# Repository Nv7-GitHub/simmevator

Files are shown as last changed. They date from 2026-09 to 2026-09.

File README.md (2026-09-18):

# simmevator

An elevator tracker and floor display for Simmons Hall, MIT.

A barometer rides in each elevator car and works out which floor the car is on. It
broadcasts that over LoRa to a bridge in its own shaft, which relays it over
ESP-NOW to a screen on every landing of that shaft. Each screen shows the floor in
numbers you can read from down the corridor, an up/down arrow while the car is
moving, the transmitter's battery voltage, and how far that elevator has travelled
in the last day.

Three shafts are covered: A, B and C. A and C serve a basement as well as floors
1-10, so they have eleven landings each; B has ten. That is 3 transmitters, 3
bridges and 32 displays.

| | elevator A | elevator B | elevator C |
|---|---|---|---|
| landings | B, 1-10 | 1-10 | B, 1-10 |
| displays | 11 | 10 | 11 |
| LoRa frequency | 913.0 MHz | 915.0 MHz | 917.0 MHz |
| ESP-NOW channel | 6 | 1 | 11 |
| `txId` | `'A'` | `'B'` | `'C'` |

The three systems are independent end to end. A car is heard only by its own
bridge, a screen only ever sees its own shaft's car, and no packet crosses from one
shaft to another.

Each car node runs on a battery, unattended, for about seven weeks.

---

## How it works

### The hard part is not what you would guess

A floor is about 2.9 m of altitude, and a BMP390 resolves that easily — noise in
this shaft is 0.045 m, sixty times smaller. The difficulty is that **the reference
pressure moves.** Over a 3 h capture in this building the sea-level reference
wandered 9.9 m of apparent altitude, more than three floor heights. Any fixed
pressure-to-floor table slides through several floors in an evening.

So absolute altitude cannot decide the floor. Two facts rescue it:

- **A trip is short** — 5 to 60 seconds, over which the weather moves the
  reference by less than 0.05 m. The *change* in altitude across a trip is clean
  even when the absolute value is not.
- **Floors are a lattice.** Every jump between stops is an integer multiple of the
  floor pitch, so `round(jump / pitch)` is a strong error-correcting code.

The algorithm therefore reads floor *changes* from jumps between stops and treats
absolute position as a slowly-tracked side quantity. It learns the building as it
goes — the floor spacing, each landing's height, how many floors exist — with
nothing configured in advance. On the reference capture it converges in five
minutes to a pitch of 2.871 m and ten floors, and stays within ±1%.

The algorithm is not this repo's invention. It was developed and measured against
real data in the [`elevatormons`](../elevatormons) bring-up repo, and is fully
documented in `elevatormons/docs/ALGORITHM.md` — including the four approaches
that were tried and failed, which are more instructive than the one that worked.
This repo ports it to C++ and builds a system around it.

### Why the decision happens in the car

The node holds the sensor, so it sees an unbroken 1 Hz stream and decides the
floor locally. It broadcasts the answer, not the raw pressure.

That one choice makes radio loss harmless. A dropped packet can only *age* what a
screen shows; it can never corrupt the floor, because the next packet carries the
current floor outright. There is no state to resync and no way for a bad link to
produce a wrong number. If the bridge decided the floor instead, every dropout
would become a correctness problem.

### The three devices

```
  ELEVATOR CAR (battery)          MID-SHAFT (wall)          EVERY LANDING (wall)
  ┌──────────────────────┐        ┌──────────────┐          ┌──────────────┐
  │ XIAO ESP32S3         │        │ XIAO ESP32S3 │  ESP-NOW │ CYD x10/x11  │
  │  BMP390 @ 4 Hz       │  LoRa  │ + Wio-SX1262 │ ───────► │ ILI9341      │
  │  FloorMonitor @ 1 Hz │ ─────► │              │  flood   │ relay + draw │
  │  model in NVS        │913/915/│ LoRa -> mesh │ ch 6/1/11│              │
  │  battery sense       │917 MHz │ origin node  │ ◄──────► │ peer relay   │
  │  Wio-SX1262          │        └──────────────┘          └──────────────┘
  └──────────────────────┘
```

One of these per shaft, three times over. The column of radio settings is the only
difference between them.

**The transmitter** samples the barometer, runs the floor algorithm, and sends two
kinds of packet: an 8-byte `STATE` every 2 seconds while the car is moving, and a
24-byte `STATS` every 60 seconds carrying battery voltage, distance travelled, and
the learned building model.

**The bridge** does nothing but listen on LoRa and re-emit over ESP-NOW. It holds
no state worth losing.

**The displays** flood packets to each other so the signal reaches floors the
bridge cannot: every screen rebroadcasts each new sequence number exactly once, up
to eight hops. Flooding rather than a fixed 5→6→7 chain means one unplugged screen
does not cut off everything above it.

### Why the three systems do not interfere

**Separate LoRa frequencies, because three cars on one frequency is pure ALOHA.**
There is no carrier sense: a transmitter that is about to send has no idea another
shaft's car is mid-packet. A STATE packet is 297 ms and goes out every 2 s while
the car is active. STATE is not gated on motion alone - it keeps running for 10 s
past every stop - so the duty fraction is the 0.90 STATE-active figure, and each
car offers `0.5 x 0.90 = 0.45` packets per second. ALOHA's vulnerable window is
two packet lengths, `2 x 0.297 = 0.594 s`, so a given packet survives two
interferers with probability `exp(-2 x 0.45 x 0.594) = 0.586` - about two STATE
packets in five lost, on top of the 5.21% the shaft already costs
(`ALGORITHM.md` §9), and concentrated in exactly the evening peak when all three
cars are busy at once. So A, B and C sit on 913.0, 915.0 and 917.0 MHz: 2 MHz of
separation against a 125 kHz occupied bandwidth, sized for a transmitter passing
close to another shaft's bridge rather than for the typical case. A per-elevator
sync word would *not* fix this and must not be mistaken for a fix - it is checked
after demodulation, so it classifies wreckage rather than preventing it.
`docs/PROTOCOL.md` carries the full arithmetic.

**Separate ESP-NOW channels, because each mesh should stay the system that was
measured.** No display ever needs another shaft's data, so the three floods run on
channels 6, 1 and 11 and each one remains the ten- or eleven-node, single-origin
flood that `docs/MESH.md` measured and tuned - so every number in it stays valid as
written. One building-wide flood instead would break
in two ways: the per-bridge `origSeq` counters would collide, because the dedup ring
tests sequence numbers for equality with no notion of who minted them, so bridge
A's frame 4113 would silently swallow bridge C's; and the 5-40 ms relay jitter
window would be swamped, since 32 displays and 3 bridges put roughly 96
transmissions of about 1.3 ms each into a 35 ms window, some 3.5x oversubscribed,
re-creating the exact collision the jitter exists to prevent. Channel isolation
makes both problems not exist rather than patching them; the only thing given up is
cross-shaft path diversity, which is worthless when the shafts are far apart.
`docs/MESH.md` works through both.

### Why the update rate is what it is

Airtime is the entire power budget. A LoRa packet at SF10 costs hundreds of
milliseconds at about 118 mA, and the car in this building is *moving* 71% of an
evening peak. Thirty days off a 10 Ah LiFePO4 pack means staying under 40 mA
average. Send a 297 ms packet every 2 s around the clock and the radio alone is
~21 mA; stay awake between samples and the baseline is ~25 mA instead of ~3 mA.
Together that is ~47 mA - the requirement is missed before anything else has
gone wrong.

Two changes fix it without making the display feel slower:

- **Transmit only while the car is moving.** Nothing changes while it is parked,
  so there is nothing to say. A 60-second heartbeat carries the slow statistics
  and proves the transmitter is alive.
- **Detect motion at 4 Hz, run the algorithm at 1 Hz.** The stillness test gets
  fast samples so motion onset is caught within 250 ms and the first packet
  fires immediately; the algorithm itself still sees the 1 Hz stream its
  constants were tuned for. Between samples the chip light-sleeps, which is the
  difference between a 3 mA baseline and a 25 mA one.

That lands at roughly **23 mA average, about 50 days** on a 10 Ah LiFePO4 pack,
using the evening-peak traffic rate — a real week including nights does better.

That is arithmetic, not a measurement. No board has been on a meter yet, and the
light-sleep floor is the number in it I would trust least: the ~3 mA is the
datasheet figure, while the actual XIAO board also carries a power LED and a
charge IC. The spec lists the four unmeasured draws and what to do about them.

### One correction to the radio settings

`elevatormons/platformio.ini` configures the barometer link at **BW62.5 kHz**, but
`ALGORITHM.md §9` records that the actual field run — the one that measured 5.21%
packet loss over three hours in this shaft — was at **BW125 kHz and only 14 dBm**.

This project uses BW125 at 22 dBm on all three shafts. The 915.0 MHz that the
bring-up repo and the field run used is now elevator B's frequency specifically -
A and C sit 2 MHz either side of it, and nothing else about the link differs
between them. That is the configuration with real in-shaft
evidence, running with 8 dB more margin than the run that produced the 5.21%
figure, and it costs 297 ms per packet instead of 725 ms. The same section notes
that loss barely tracks signal-to-noise (r = −0.13) — it is shadowing and
interference, not a decode floor — so buying margin with a higher spreading factor
would cost airtime linearly and buy very little.

---

## What each screen shows

```
┌────────────────────────────┬──────────────┐
│                            │      ▲       │
│      ██████     ██         │    UP        │
│      ██  ██     ██         │              │
│      ██  ██     ██         │  12.7 V      │
│      ██  ██     ██         │  ■■■■■□      │
│      ██████     ██         │              │
│                            │  2.1 mi      │
│                            │  today       │
└────────────────────────────┴──────────────┘
```

The floor number is drawn as vector segments rather than a font — anything large
enough to read at distance looks soft as a bitmap. While the car is moving the
number sweeps through the intermediate floors and the arrow lights up; on arrival
it snaps to the floor the algorithm confirmed.

Battery voltage and the 24-hour distance come from the transmitter once a minute,
so every screen in that shaft agrees. Between heartbeats each screen extrapolates
the distance from floor changes it observes, so the number ticks in real time
rather than jumping once a minute.

If a screen stops hearing the mesh it dims, then greys out and turns its onboard
LED amber — a dead link is visible from the corridor rather than silently showing
a floor from twenty minutes ago.

That is normal operation. There are three further states that appear only while a
shaft is being commissioned or is misconfigured, all derived from fields the wire
already carries: **LEARNING**, showing how many landings the car has spanned so far
over the word `LEARNING` and `OF 11`; **ANCHORING**, asking for a ride to both ends of the shaft
after the transmitter restored its model from NVS; and **CHECK SHAFT**, which means
the car is confidently reporting a floor count this shaft does not have. The last
one is the whole reason the others exist. An elevator A car commissioned over a
period in which nobody presses B learns a span of ten landings, is internally
consistent, sets its model ready, and would label every screen in the shaft one
floor too low indefinitely - and it is the display, holding the only copy of how
many landings the building has, that can catch it. That mismatch is CHECK SHAFT's
only cause, and because every display in a shaft carries the same label table and
hears the same bridge, it appears on all of them at once or on none. It does not
catch a mis-flashed display: the mesh channels are 6, 1 and 11, which do not
overlap, so a display flashed for the wrong shaft never hears its landing's bridge
at all and sits on the splash screen forever. `docs/FLASHING.md` has the
commissioning procedure. `--` means "this screen has heard frames but has no
confirmed floor"; a screen that has heard nothing since boot still shows the
splash.

---

## Documentation

| Document | What is in it |
|---|---|
| [Design spec](docs/superpowers/specs/2026-09-11-simmevator-design.md) | The whole system: power budget, protocols, verification gates, parts list |
| [Three-elevator deployment](docs/superpowers/specs/2026-09-18-three-elevator-deployment-design.md) | The per-shaft frequency and channel plan, the basement, the commissioning screens |
| [docs/HARDWARE.md](docs/HARDWARE.md) | Wiring, the battery divider, the buck regulator, antenna placement |
| [docs/FLASHING.md](docs/FLASHING.md) | Which firmware goes on which board, and how |
| [docs/PROTOCOL.md](docs/PROTOCOL.md) | Both wire formats, field by field |
| [docs/MESH.md](docs/MESH.md) | How the ESP-NOW flood behaves and how to debug it |
| [docs/ALGORITHM_PORT.md](docs/ALGORITHM_PORT.md) | How the C++ port maps to the Python reference, and the evidence it matches |
| `elevatormons/docs/ALGORITHM.md` | The algorithm itself — the source of truth, not maintained here |

---

## Building

PlatformIO. Nine firmware environments - three roles across three elevators:

```bash
pio run -e elevator_tx_b   -t upload    # shaft B's car node
pio run -e bridge_rx_b     -t upload    # shaft B's bridge
pio run -e floor_display_b -t upload    # each of shaft B's screens
pio test -e native                      # host unit tests
```

Substitute `_a` or `_c` for the other two shafts. The suffix is the whole of an
image's identity: it carries the LoRa frequency, the ESP-NOW channel, the `txId`
and the floor label table, so a display built `_b` and hung in shaft A is deaf on
channel 1 while that landing's bridge floods channel 6, and never leaves its splash
screen. There is no runtime elevator selection to correct it with.
`docs/FLASHING.md` has the which-image-on-which-board table, the board labelling,
and the commissioning check that catches exactly that mistake.

The port is verified by replaying the real 3 h capture through the actual C++
implementation and diffing it against the Python reference sample by sample:

```bash
pio run -e sim && .pio/build/sim/program sim/cpp_broadcasts.csv
python3 sim/compare_to_python.py sim/cpp_broadcasts.csv
```

The gate that matters is the first line of the comparator's output: the C++
floor sequence has to be identical to the Python's over all 10,950 samples. Five
numeric gates bound the rest - ten floors, 2.871 m pitch ±1 mm, 3409 m travelled
±0.1%, 357 floor-to-floor moves ±1, 255 confirmed stops ±1.

`ALGORITHM.md` §5 reports 356 moves and 256 stops, and that is not a
disagreement: §5 measured the raw capture, which is a radio log with 49 dropouts
in it, while the replay runs the gap-filled 1 Hz stream the node would actually
have been handed. The Python reference produces 357/255 on that input too.
`docs/ALGORITHM_PORT.md` §6 works through it.

---

## What this will not do

- **There is no absolute anchor.** The floor index is integrated from jumps, so a
  rounding that goes wrong stays wrong until the car happens to correct it. An
  absolute readout from a tracked datum was tried and is measurably worse.
- **It is safe to about 3 hPa/h of pressure change** with the floor count still
  exact, and degrades rather than diverges past that. A typical weather front is
  1–2 hPa/h; the fastest rate in the reference capture was 0.88 hPa/h.
- **Turbulence headroom is roughly 1.5–2×** a confirmed gusty evening. Not zero,
  not large.
- **The constants are tuned to this building and this sensor.** They are measured,
  not universal.
- **Battery voltage is ±2–3% before calibration**, about ±0.4 V at 12 V. Enough to
  answer "does this need charging?", not a fuel gauge.
- **The 24-hour window is relative to uptime**, not wall-clock — there is no RTC.
  After a reboot it reports less than a day of history and says so.
- **A screen shows one car.** A landing served by all three shafts needs three
  screens, one per shaft. There is no "which car arrives first" logic anywhere in
  the system, and there cannot be without building one: each display is on its own
  shaft's mesh channel and physically never hears the other two cars.

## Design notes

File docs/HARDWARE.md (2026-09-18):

# Building the hardware

Three device types, built in this order: the transmitter (the only one with any
wiring in it), the bridge (twenty minutes, mostly deciding where to put it), and
the displays (unbox, plug in).

Three shafts, not one. Elevators A and C have a basement landing and eleven
displays each; elevator B is the ten-landing shaft this system was first built
for, and is unchanged in every respect.

| device | where it lives | power | what it does |
|---|---|---|---|
| transmitter ×3 | on top of / inside each elevator car | LiFePO4 4S pack | reads the barometer, decides the floor, transmits LoRa |
| bridge ×3 | one per shaft, floor 5 (section 6) | USB-C wall adapter | receives LoRa, floods it over ESP-NOW |
| display ×32 | one per landing per shaft: A 11, B 10, C 11 | USB-C wall adapter | shows the floor, relays the mesh |

**The three builds are mechanically identical.** Nothing in sections 2 to 5
differs between A, B and C - the same stack, the same divider, the same buck,
the same calibration procedure, the same charger, the same enclosure. The only
thing that differs is which firmware image goes on the board, and which shaft
the finished board is carried to. So those sections are written once and mean
all three; where one says "the transmitter", build three of them.

Everything below is drawn from the design spec
(`docs/superpowers/specs/2026-09-11-simmevator-design.md`), the three-elevator
deployment spec
(`docs/superpowers/specs/2026-09-18-three-elevator-deployment-design.md`),
`platformio.ini`, and the module headers in `src/`. Where a number is not from
one of those, it says so.

---

## 1. Parts

Reproduced from spec section 3.6. This list has already been trimmed once - see
the note after the tables before you add anything back.

**Transmitter (×3 assemblies; the Qty column is per assembly)**

| Part | Qty | Notes |
|---|---|---|
| Seeed XIAO ESP32S3 | 1 | |
| Seeed Wio-SX1262 for XIAO | 1 | stacks onto the XIAO; ships with its 915 MHz antenna |
| BMP390 breakout | 1 | Adafruit 4816 or equivalent |
| LiFePO4 12.8 V 10 Ah pack with BMS | 1 | 4S; BMS required |
| LiFePO4 charger, 14.6 V | 1 | a Li-ion or lead-acid charger will not terminate correctly |
| MP1584EN 5 V buck module | 1 | meter it at 5 V **before** connecting the XIAO |
| Resistor 100 kΩ 1% | 1 | divider top |
| Resistor 20 kΩ 1% | 1 | divider bottom |
| Spade terminal pair | 1 | so the pack can come off for charging |
| Hookup wire / JST leads | — | |

No divider filter cap (oversampled in software instead), no buck input
electrolytic (the node averages ~23 mA, so the module's own ceramics are
sufficient), and no inline fuse (the pack's BMS covers overcurrent). The
enclosure is 3D printed.

**Bridge (×3, one per shaft; Qty is per bridge)**

| Part | Qty |
|---|---|
| Seeed XIAO ESP32S3 | 1 |
| Seeed Wio-SX1262 for XIAO | 1 |
| USB-C 5 V adapter + cable | 1 |

**Displays (×32, all three shafts)**

| Part | Qty | Notes |
|---|---|---|
| ELEGOO ESP32 CYD 2.8" ILI9341 240×320 | 32 | sold in 2-packs → 16 packs |
| USB-C 5 V / 1 A adapter | 32 | |
| USB-C cable | 32 | |

32, not 30: **A 11 + B 10 + C 11 = 32**, because A and C each have a basement
landing and B does not. Count the landings, not the shafts - ordering 30 because
"three tens" is the easy mistake, and it leaves the two basements dark.

Mounts are 3D printed.

**Totals to buy:** 6 × XIAO ESP32S3 · 6 × Wio-SX1262 · 3 × BMP390 · 3 × battery +
charger · 3 × MP1584EN · 6 × resistors · 3 × spade pair · 32 × CYD · 35 × USB-C
supplies. Three enclosures and 32 display mounts are printed.

The USB-C count is 32 displays + 3 bridges = 35; the transmitters run off their
packs and take no adapter. Note that the build does not simply triple: the
electronics scale ×3, but the displays scale ×3.2, and the displays are the bulk
of the parts count. The two basement landings are the whole of that difference.

### 1.1 Where is the fuse?

The four things a reader usually expects to find in this list and does not:

| left out | why |
|---|---|
| inline fuse | the pack's BMS is the overcurrent and undervoltage protection. It is inside the pack, on the cell side of the terminals, and it is the reason the pack has to be a BMS pack rather than four bare cells. |
| buck input electrolytic | the node averages ~23 mA. The MP1584EN module's own input ceramics handle that; the electrolytic is there for modules running amps. |
| filter cap across the divider bottom leg | the reading is taken once a minute off a rail that moves over hours. The filtering is done in software instead: 32 samples, median not mean (spec 3.2, `battery.h`). A median also throws away the occasional wild sample the S3's SAR ADC produces, which a capacitor would not. |
| barrel jack, separate antennas, enclosure, display mounts | the Wio-SX1262 ships with its antenna; the three enclosures and the 32 mounts are 3D printed; the pack connects through spade terminals so it can come off for charging without a connector in the middle. |

If you decide to add the fuse anyway, put it on the pack side of the spade pair
so it protects the wiring and not just the buck.

### 1.2 Tools

Not in the parts list, but you cannot do section 3 without them:

- **A multimeter.** Non-negotiable. Section 3.4 is entirely a meter procedure.
- Soldering iron, thin solder, heat-shrink.
- A small flat screwdriver or trimmer tool, if your buck module has a trimpot
  rather than a fixed 5 V output.
- Wire strippers, and a crimp tool if your spade terminals are crimp type.
- A USB-C cable for flashing - and a habit of not having it plugged in at the
  same time as the pack (section 3.5).

---

## 2. Transmitter pinout

Everything the car node uses, in one table. From spec 3.1, `lora_link.h`, and
`platformio.ini`.

| signal | XIAO pad | GPIO | where it comes from |
|---|---|---|---|
| BMP390 SDA | D4 | 5 | your wire |
| BMP390 SCL | D5 | 6 | your wire |
| SX1262 SCK / MISO / MOSI | D8 / D9 / D10 | 7 / 8 / 9 | the stack, no wire |
| SX1262 NSS / DIO1 / BUSY / NRST | - | 41 / 39 / 40 / 42 | the stack, no wire |
| battery sense | D0 | 1 (ADC1_CH0) | your divider |
| 5 V in | 5V | - | the buck |
| ground | GND | - | common with the pack minus |

The BMP390 runs on `Wire1` at 400 kHz, address 0x77. The radio is SF10 / BW125 /
CR4-8 at 22 dBm on all three systems; only the centre frequency differs - 913.0
MHz on A, 915.0 MHz on B, 917.0 MHz on C, for the collision reasons in spec 2.1.
That is a build flag, not a wiring difference. The board you solder is the same
board whichever shaft it ends up in.

---

## 3. Transmitter assembly

Build in this order. Each step is testable before the next one adds a way for
it to fail.

### 3.1 Stack the radio onto the XIAO

The Wio-SX1262 is an expansion board for the XIAO form factor. There is no
wiring: the SPI bus and the four control lines in the table above all run
through the two 7-pin headers.

1. Match the silkscreen. **D0 must sit over D0 and GND over GND.** Both boards
   label their pads; check two on opposite corners before you press them
   together, because the headers will physically mate either way round and the
   wrong way puts the pack rail onto a control line.
2. Press them home evenly. They should sit flat with no gap.
3. Screw the 915 MHz antenna that came with the Wio-SX1262 onto its connector.
   It is a band antenna, not a spot-tuned one, and 913.0 / 915.0 / 917.0 MHz all
   sit deep inside the 902-928 MHz ISM band - so the same antenna serves all
   three shafts and there is nothing to select here.

**Do not power the radio without the antenna attached.** That is general RF
practice rather than anything measured here - an unterminated PA reflects its
own output back into itself.

Also, from the note in `platformio.ini` next to `LORA_TX_POWER=22`: the
SX1262's absolute maximum RF input is around **+10 dBm**, and the transmitter
puts out 22 dBm. On a bench the only thing between those two numbers is path
loss, and at 915 MHz free space gives:

| separation | at the receiver |
|---|---|
| 0.10 m | +10.3 dBm - **over the absolute maximum** |
| 0.25 m | +2.4 dBm |
| 0.50 m | -3.6 dBm |
| 1.00 m | -9.7 dBm - about 20 dB of margin |

The crossover is 0.104 m. **Keep at least 1 m between any transmitter antenna
and any bridge antenna whenever both are powered**, which is a minimum and not a
target - further is always safer. Two boards side by side on a bench sit 5-10 cm
apart, which is past the absolute maximum, and what it costs is a damaged
receiver front end that then under-performs quietly rather than failing
outright. The bench test in `FLASHING.md` is written around this minimum.

### 3.2 BMP390, four wires

| BMP390 breakout | XIAO |
|---|---|
| VIN | 3V3 |
| GND | GND |
| SDA (SDI on Adafruit's silkscreen) | D4 |
| SCL (SCK on Adafruit's silkscreen) | D5 |

Leave SDO alone. Floating or pulled high gives address 0x77, which is what
`platformio.ini` sets. If your breakout straps it low you get 0x76, and
`bmp390BringUp()` falls back to that address and reports the mismatch on the
serial console rather than hiding it - so a board strapped the other way still
works, it just tells you.

Keep the leads short. The bus runs at 400 kHz and there is no reason for it to
be longer than it needs to be.

Sensor placement matters more than it looks. `bmp390_sensor.h` notes that this
is the module the 3 h reference capture was taken with, and that the Bosch
indoor-navigation preset it configures (x8 pressure, x2 temperature, IIR 3,
~5 cm of altitude noise) is what every constant in `floor_monitor.h` was tuned
against. The stillness threshold is 0.08 m, sitting in the gap between ~0.05 m
of stop noise and a car doing up to 1.78 m/s (ALGORITHM.md sections 2 and 5).
Substituting a noisier part - a BMP280, say - does not degrade the system
gracefully, it invalidates the tuning. Fit the BMP390.

Mount the sensor near where the enclosure's vent will be (section 3.6) and not
pressed against the buck module. The vent is what lets it see shaft pressure at
all; sitting it on the warmest thing in the box is an unmeasured risk rather
than a measured one, but it costs nothing to avoid.

### 3.3 The battery sense divider

From spec 3.2:

```
  BATT+ ──[ R1 = 100 kΩ 1% ]──┬── D0 (GPIO1)
                            │
                       [ R2 = 20 kΩ 1% ]
                            │
  BATT− ──────────────────── ┴── GND (common with XIAO GND)
```

Ratio 6.0. Use 1% parts: the ratio is the calibration, and section 4 corrects
one unit's error, not a drifting one.

What the ADC pin actually sees, computed from that ratio:

| pack | pin | meaning |
|---|---|---|
| 14.6 V | 2.433 V | a charger at its termination voltage |
| 13.3 V | 2.217 V | rested full |
| 12.8 V | 2.133 V | CHARGE SOON, ~20% remaining |
| 12.0 V | 2.000 V | CHARGE BATTERY, ~10% remaining |
| 10.0 V | 1.667 V | BMS cutoff territory |

The whole span sits inside the ESP32-S3 ADC's linear region at 12 dB
attenuation, which misbehaves below ~0.15 V and above ~2.8 V. That is the point
of this ratio: not to use the full scale, but to keep both ends of
the pack's range comfortably inside the part of the range that behaves, with
headroom at the top for a charger that overshoots.

Divider draw is ~122 µA at 14.6 V, which is about 0.5% of the ~23 mA average
the 30-day budget is built on - roughly a quarter of a day off the ~50-day
figure. That is why there is no switching MOSFET across it -
the switch would cost more parts and more ways to fail than it saves.

**Why kilohms and not megohms.** With no filter capacitor, the ADC's internal
sample capacitor charges straight through the divider's Thevenin resistance -
R1 ∥ R2, ~16.7 kΩ here. At 1 MΩ / 200 kΩ that would be ~167 kΩ, slow enough
that each sample can read low and pick up more noise. The ratio, and so every
voltage in the table above, is unchanged.

**Why D0 and not somewhere else.** D0 = GPIO1 = ADC1_CH0 is the only free ADC1
pad on this board:

| pad | taken by |
|---|---|
| D4 / D5 | the BMP390's I²C bus |
| D8 / D9 / D10 | the radio's SPI |
| GPIO39 / 40 / 41 / 42 | the radio's DIO1, BUSY, NSS, NRST |

It has to be ADC1 rather than any ADC. `battery.h`: ADC2 is unusable while WiFi
is active, and while the car node itself does not run WiFi, the bridge and the
displays do - the constraint is written into the shared design so the choice is
the same everywhere.

There is deliberately no capacitor here. See section 1.1.

### 3.4 Check the buck regulator's output

The buck feeds the XIAO's **5V pad**, not its 3V3 pad. The 3V3 pad is the
output of the XIAO's own regulator, so driving it means fighting that regulator;
the 5V pad is the board's supply input, which that regulator exists to convert.

> ### STOP. This is the step that destroys hardware.
>
> The module is sold as a fixed 5 V output, but check it before you believe it.
> Some MP1584EN boards carry a trimpot instead, and one of those arrives set to
> **whatever position it was left in on the production line**. The adjustment
> range runs from under a volt to within shouting distance of the input, so fed
> from a 12.8 V pack a mis-set module can put far more than 5 V onto the pad.
>
> The XIAO's own regulator stands between that pad and the chip, so it takes
> the hit first - but it is an SGM6029, rated for 5.5 V in. There is almost no
> headroom above 5 V, and past it the failure reaches the silicon behind it.
>
> **Meter the output with nothing connected to it. Only then wire it to the
> XIAO.**
>
> Check the XIAO ESP32S3 datasheet's input rating before you decide a reading
> is close enough; this document deliberately does not quote you a number to
> feel comfortable about.

Procedure:

1. Disconnect the buck's output from **everything**. No XIAO, no BMP390, no
   divider top leg. Nothing but two bare wires.
2. Wire the pack to the buck input through the spade pair, minding polarity.
   IN+ to pack positive, IN− to pack negative.
3. Meter across the buck's OUT+ and OUT−, DC volts, on a range that covers
   15 V - not a 3 V range that will just say "OL" if the output is high.
4. It should read **5.0 V**. If it does and the board has no trimpot, you are
   done with this step.
5. If the board does have a trimpot, turn it in small increments and watch the
   meter. Do not assume which way is up, and do not assume a quarter turn will
   do anything: some of these modules carry multi-turn trimmers and take many
   revolutions to cross the range. Turn, read, turn, read. Land on **5.0 V**.
6. Disconnect the pack. Wait, re-connect, and confirm it still reads 5 V.

The MP1584 is PWM-only with no light-load PFM mode (spec 3.3), so it does not
pulse-skip and the no-load reading you just took is representative of the
loaded one. Re-measure once with the node running anyway, at the XIAO's 5V pad
rather than at the buck, so the measurement includes your wiring.

That same PWM-only behaviour is why the node's ~3 mA light-sleep current is
served badly by this module. It runs ~80-85% at the ~23 mA average. A TPS62203
or MP2338 would recover a few days. Not required.

### 3.5 Wire the buck to the XIAO, and never plug in USB at the same time

Only after section 3.4 reads 5 V:

1. Buck OUT+ → XIAO **5V** pad.
2. Buck OUT− → XIAO **GND**, and the same ground node as the divider's bottom
   leg and the pack minus. One ground, not two.
3. Divider top leg to pack positive on the buck-input side of the spade pair,
   so the divider measures the pack and not the buck.

The power chain, end to end (spec 3.3):

```
LiFePO4 4S 10 Ah → spade terminals → MP1584EN buck at 5 V → XIAO 5V pad
  → XIAO's onboard SGM6029 buck → 3.3 V for the chip, the radio and the BMP390
```

**The second conversion costs about a tenth of the battery.** The XIAO's
onboard regulator is an SGM6029 synchronous buck - not a linear regulator - with
a power-save mode and 2.3 µA of quiescent current, so at these loads it is worth
roughly 85-90% rather than the 66% a linear part would manage. Behind the
module's own ~85%, the pack sees about 7.9 mA for the node's 23 mA average,
which is ~50 days against the ~56 the same node would get if the 3.3 V rail
could be fed directly. Feeding 3V3 would recover those few days at the cost of
back-driving that regulator, which is why it is not done here. Both efficiency
figures are datasheet-grade estimates, not measurements.

> **USB and the buck must never be connected at the same time.**
>
> The XIAO's 5V pad and its USB connector's VBUS are the same node. Connect
> both and the buck's output is tied directly to the host's 5 V rail - two
> supplies across each other, and the buck's output is also back-fed into
> whatever you are flashing from.
>
> The 12.8 V pack has the energy to keep doing that indefinitely. It may
> survive; it may take out the buck, the XIAO, or the USB port on your
> computer. It is not a failure with a predictable outcome, which is exactly
> why it is not worth characterising empirically on your only XIAO.
>
> **Unplug the pack at the spade terminals before you plug in USB.** Every
> time. That is what the spade pair is for as much as charging is.

### 3.6 The enclosure must be vented

The enclosure is 3D printed, so this is a note for whoever draws it.

**A sealed box turns the barometer into a thermometer and the system stops
working.** Inside a sealed volume the pressure the BMP390 reads is set by the
temperature of the air trapped with it, not by the altitude of the car. Every
constant in the algorithm is measured against shaft pressure.

What is needed is modest: a small hole with a scrap of foam or filter cloth
over it. It has to equalise on the timescale of seconds, not breathe freely.
The car moves a floor in a couple of seconds and the algorithm's stillness
window is 5 samples at 1 Hz, so a vent with a time constant of seconds is
invisible to it and a vent with a time constant of minutes is fatal to it.

Design notes for the print:

- Vent placed away from the buck module, and near where the BMP390 sits.
- Cloth or foam over the hole - it is there to keep dust and drafts off the
  sensor port, not to seal.
- The pack comes out for charging, so the spade pair has to be reachable
  without dismantling the electronics.
- The antenna wants to be outside the box, or at least not wrapped in it.

---

## 4. Calibrating the battery reading

Uncalibrated, the divider is worth ±2-3%, about ±0.4 V at 12 V (spec 9). That
answers "does this need charging?" and is not a fuel gauge. A one-point
correction with a DMM gets most of it back, and it takes two minutes.

The firmware applies a plain integer ratio to the computed pack voltage:

```
reported_mV  =  pin_mV × (R1 + R2) / R2 × VBAT_CAL_NUM / VBAT_CAL_DEN
```

`VBAT_CAL_NUM` and `VBAT_CAL_DEN` both default to 1 in `platformio.ini`, which
means uncalibrated.

**Procedure**

1. Assemble the node and power it from the pack. Let it settle - a pack just
   off the charger is still relaxing.
2. Meter the pack directly at the spade terminals. Write it down in millivolts.
   Call it `TRUE`.
3. Read what the node thinks. The serial console is the place to get it: the
   display's readout is rounded to 0.1 V (spec 6) and that is too coarse to
   calibrate against. Call it `REPORTED`.
4. Set:

```
-DVBAT_CAL_NUM=TRUE
-DVBAT_CAL_DEN=REPORTED
```

5. Rebuild and reflash (pack disconnected - section 3.5).
6. Re-read. It should now agree with the DMM to within the ADC's own noise.

**Worked example.** The DMM reads 13.28 V at the terminals. The node reports
13112 mV. Then:

```
-DVBAT_CAL_NUM=13280
-DVBAT_CAL_DEN=13112
```

and the node's next reading becomes 13112 × 13280 / 13112 = 13280 mV. The
correction is 1.28% high, which is exactly the order of error the ±2-3%
uncalibrated figure predicts.

Use the raw millivolt integers. Do not reduce them to a rounded percentage -
the maths is integer division, and `13280/13112` carries more resolution than
`101/100` does. The intermediate is computed in 64-bit, so there is no headroom
problem with numbers this size.

This is **per unit**, and there are now three units. It corrects the resistors
you actually soldered and the eFuse calibration curve of the chip you actually
have, so each of the three transmitters carries its own pair of numbers and they
will not agree with each other.

Nothing in the firmware can tell the boards apart, which is what makes this
worth a warning rather than a footnote: a ratio measured on A's board and
compiled into C's image does not fail, it reports a confidently wrong pack
voltage on eleven screens, and it does so most convincingly near the thresholds
in section 5 where the curve is flat. Record which pair belongs to which shaft,
in the repo, alongside that elevator's other build flags - the per-elevator
transmitter environments are the natural place for them.

---

## 5. Charging the pack

**14.6 V LiFePO4 charger. Nothing else.**

| charger type | why not |
|---|---|
| Li-ion / LiPo | charges to 4.2 V per cell. A 4S Li-ion charger terminates around 16.8 V, which is well above the 14.6 V a 4S LiFePO4 pack wants. |
| lead-acid / "12 V car battery" | wrong termination behaviour. Lead-acid chargers hold a float voltage indefinitely and some apply temperature compensation or an equalise stage; LiFePO4 wants constant current to 14.6 V, then to be left alone. |

Those chemistry voltages are standard figures, not measurements from this
project. The one number this project does specify is the 14.6 V termination in
spec 3.6.

The pack's BMS will defend itself against a lot of this, and you should not
make it. A BMS disconnecting on overvoltage mid-charge is a fault condition,
not a charging strategy.

**Disconnect the pack at the spade terminals before charging.** The spade pair
exists for exactly this.

What the rest of the system does while it is off, and when it comes back:

| | screens |
|---|---|
| pack off | keep the last floor for 2.5 min, dim, then at 3 min grey out with the LED amber. A CHARGE BATTERY warning stays red throughout |
| pack back on | within a minute the STATS heartbeat arrives, the screens un-grey, and a charged pack clears the battery warning. No pairing, nothing to press |
| until the car visits **both ends of its own shaft** | the screens read **ANCHORING / RIDE TO BOTH ENDS** in place of the floor |
| after that | normal |

ANCHORING is deliberate, and it is not a fault: it is the screen saying the
model came back out of flash intact but the car's position is not yet known, and
it clears itself the moment the car has seen both ends. The transmitter keeps
the learned building across a reboot, but not the car's position: the car may
have moved and the weather will
have shifted the pressure reference, and a floor restored one out would stay one
out forever. Seeing both ends of the shaft fixes the position exactly. **So
after reconnecting, ride to the lowest landing and the highest.**

Which landings those are is per shaft. In B they are floors 1 and 10. In A and C
the bottom end is the **basement**, not floor 1: stopping at floor 1 leaves the
seen span one landing short of the learned span, the anchor never locks, and the
screens go on reading ANCHORING indefinitely. That is the failure mode to watch
for - not a wrong floor, but a shaft where the request on the glass never goes
away because the ride it asks for was never completed. Either order works - bottom-then-top and top-then-bottom are the same operation, and
neither the code nor the procedure prefers one.

It does not correct itself over time without that, and it does not need to - the
first time the car naturally visits both ends it locks in.

### Voltage to state of charge

From spec 3.2, set in `battery.h` as `VBAT_WARN_MV` / `VBAT_CRITICAL_MV` /
`VBAT_CHARGED_MV`:

| voltage | what every screen shows | notice at ~23 mA |
|---|---|---|
| 13.3 V | rested full - clears any warning | - |
| **12.8 V** | **CHARGE SOON**: amber badge in place of the battery bar, voltage in amber | ~3 days (~20% left) |
| **12.0 V** | **CHARGE BATTERY**: steady red banner across the bottom, red badge, onboard LED steady red | under 2 days (~10% left) |
| ~10 V | the BMS disconnects the pack and the car node goes silent | - |

Each 10% of a 10 Ah pack is about 1.8 days at the budgeted draw, so these give
less notice than the voltages suggest. An earlier version warned at 12.0 V
believing it was ~20%; it is nearer 10%.

The warning **latches**. Once a reading crosses a threshold the level stays up,
even if a later reading wobbles back above it, and clears only when the pack
reads 13.3 V - which in practice means it has been charged. A warning that
disappeared by itself would be the easy one to miss. The latch lives on the
transmitter, and the level travels in the STATS flags, so every screen in that
shaft agrees - eleven of them in A and C, ten in B. It travels no further than
that: the three meshes are on separate channels, so a flat pack in A is invisible
on B's and C's screens, as it should be.

A warning also does not grey out when the link goes stale, although everything
else on the screen does. If the car node goes silent right after CHARGE BATTERY,
the likeliest reason is that the battery ran out, and that is the moment the
warning should stay on the screen.

The thresholds sit on the flat part of the curve, where ±2-3% uncalibrated
accuracy is about ±0.4 V. **Do the one-time calibration** (above) or CHARGE SOON
may come days early or not until CHARGE BATTERY.

Expect to charge roughly every seven weeks if the node is behaving: spec 2
budgets ~23 mA average at evening-peak traffic, which is ~50 days through the
module and the XIAO's own regulator, against a 30-day requirement.

---

## 6. Bridge

Mechanically trivial, and the three are built identically. The only decision is
where each one goes.

1. Stack the Wio-SX1262 onto the XIAO exactly as in section 3.1, silkscreen
   matched, antenna screwed on.
2. Flash it with the image for its shaft - `bridge_rx_a`, `bridge_rx_b` or
   `bridge_rx_c`. The environment carries that shaft's LoRa frequency and mesh
   channel, so a bridge flashed with the wrong image does not degrade, it hears
   nothing at all - and because its mesh channel is wrong too, its displays
   never hear a frame either and sit on the splash screen. `FLASHING.md` has
   the table and the upload commands; do not keep a second copy of them here.
3. Label the board with its shaft letter before it leaves the bench, in the same
   motion as flashing it (section 7).
4. Plug it into a USB-C 5 V adapter on floor 5 of its own shaft. It sits in
   continuous LoRa receive and floods what it hears over ESP-NOW, so it wants to
   stay powered.

**Antenna placement is the part that matters.** ALGORITHM.md section 9 measured
the link and found that loss barely tracks SNR at all (r = −0.13): 5.21% batch
loss over 3 h, 49 dropouts, and even above +6 dB of margin there is still 0.3%
loss. That is shadowing and interference, not a decode floor - which is why
this project spends power on bandwidth and TX power rather than on spreading
factor.

The exception is floor 9. It is the one landing whose SNR range crosses the
SF10 decode floor, bottoming at −2.0 dB against a healthy +14.2 dB median. An
intermittent shadow, and section 9's own conclusion is that it is addressable
by antenna placement rather than by spreading factor.

So:

- Favour line of sight up the shaft. The bridge is on floor 5 and the problem
  landing is above it.
- Get the antenna out of the cabinet, out from behind the steel door, away from
  the ductwork.
- Vertical, and clear of large metal for as much of its length as you can
  manage.
- If floor 9 still shows staleness in service, move the bridge antenna before
  you touch any radio setting. The measurement says placement is the lever.

The bridge also has to reach at least one display over ESP-NOW, since it is the
origin of the flood. In practice the floor 5 display is next to it, so this is
rarely a constraint - but do not put the bridge somewhere the mesh cannot
follow it.

### 6.1 Is floor 5 still the middle when the shaft has a basement?

Worth doing the arithmetic rather than assuming, because A and C have an extra
landing at the bottom and the instinct is to compensate by dropping their
bridges to floor 4.

Count landings, not floor numbers. B's shaft has ten landings, an even count, so
there is no single middle one: the centre falls between floors 5 and 6, and
floor 5 was chosen of the two deliberately, because the weak landing sat above
and biasing upward cost nothing. A and C have eleven landings, an odd count, so
there **is** an exact middle landing - the sixth. Counting up from the bottom:
B, 1, 2, 3, 4, 5. The sixth landing is floor 5.

| shaft | landings | count | middle | bridge | landings above | landings below |
|---|---|---|---|---|---|---|
| A | B, 1-10 | 11 | the 6th = floor 5 | floor 5 | 5 | 5 |
| B | 1-10 | 10 | between floors 5 and 6 | floor 5 | 5 | 4 |
| C | B, 1-10 | 11 | the 6th = floor 5 | floor 5 | 5 | 5 |

**Floor 5 is still the right answer, and in A and C it is a better one than it
is in B** - it is the exact centre rather than the lower of two candidates. The
extra landing at the bottom moves the midpoint down by half a landing, from
halfway between floors 5 and 6 to floor 5 itself. Half a landing is not a
relocation. Dropping those bridges to floor 4 would move them away from the
centre and away from the upper shaft at the same time, for no gain.

The furthest any display sits from its bridge is therefore 5 landings in all
three shafts, which is what section 7's hop-limit slack is computed against.

One caution about floor 9. `ALGORITHM.md` section 9 is a 3 h capture in **one**
shaft, taken when this was a one-shaft building. It says where that shaft's
shadow was; it does not predict where A's or C's will be, because steel,
ductwork and cabinet placement differ landing by landing. Carry the shape of the
finding into the other two shafts - one or two landings will be markedly worse
than the median, and the fix is antenna placement rather than a radio setting -
but do not carry the coordinate. Each shaft reveals its own weak landing in
service, by the greyed-out screen and amber LED in section 7.

---

## 7. Displays

32 ELEGOO CYD boards across three shafts - eleven in A, ten in B, eleven in C.
USB-C power and nothing else: no wiring, no soldering, no sensors. Flash each one
with its shaft's image (`floor_display_a`, `floor_display_b` or
`floor_display_c`), mount it, and plug it into a 5 V / 1 A adapter. The upload
commands and the which-image-on-which-board table are in `FLASHING.md`.

**Label every board with its shaft letter before it leaves the bench.** Not
afterwards, not from memory - in the same motion as flashing it, while the
programmer is still attached. The image sets both the mesh channel and the
label table, and nothing on the outside of a CYD says which it got.

A board flashed for the wrong shaft is **deaf**, not wrong. The mesh channel is
part of the image - 6 for A, 1 for B, 11 for C - and 1, 6 and 11 are the
non-overlapping channels, so such a board cannot hear its landing's bridge at
all. It never leaves `displaySplash("Simmevator", "waiting for the mesh")`: a
screen that simply never comes up. That is the whole protection, and it is a
good one precisely because it fails visibly: the first time the board is
powered on its landing with the shaft running, it is obviously dead next to
neighbours showing floors. What it cannot tell you is *which* shaft the board
was built for, and it cannot tell you anything at all at the bench, where every
board is out of range of its bridge and shows the same splash. The written
letter is what tells you the shaft, which is why it goes on in the same motion
as the flash.

CHECK SHAFT is not the defence here and cannot be: a deaf board renders nothing
to check. CHECK SHAFT is a statement about the **car**, not the display - the
car's learned `nFloors` disagrees with the shaft's `FLOOR_LABEL_COUNT`, in
practice a car that has never visited its lowest landing. Every display in a
shaft carries the same label table and hears the same bridge, so CHECK SHAFT is
all-or-nothing across the shaft: it appears on every screen at once or on none.
One odd screen out of ten or eleven is never CHECK SHAFT.

**The mesh is the constraint on where they go.** There is no WiFi network here
and no router. Every display has to hear either its bridge or another display in
its own shaft directly, over ESP-NOW on that shaft's channel - 6 for A, 1 for B,
11 for C - and then relay onward. Spec 4.2:

- Flood rules are identical on the bridge and every display in that shaft; each
  node relays each new `origSeq` exactly once.
- Hop limit 8. Five landings is the furthest any display sits from its bridge in
  any of the three shafts (section 6.1), so 8 leaves slack for a detour around a
  dead node.
- `WIFI_PROTOCOL_LR`, Espressif's long-range PHY, is worth about 7 dB over
  802.11b - which is the margin that makes floor-to-floor through concrete
  work at all.

Which means:

- **Do not mount a display inside a metal enclosure.** A shielded box around an
  antenna defeats the mesh, and because the flood is multi-hop it does not just
  break that one screen - it can remove the path the screens above it were
  relying on.
- **Do not put one behind a steel fire door** and expect it to hear the bridge
  through it.
- Prefer a position in the corridor with a path toward the stairwell or the
  shaft, and toward the floors above and below.
- The 3D-printed mounts should hold the board with its back open to the
  corridor, not sandwiched against a steel frame.

**The three meshes never help each other.** They are on separate channels by
design, so a display in A cannot be rescued by a well-placed display in C however
close the two shafts pass. Each shaft's mesh has to stand up on its own, and a
mounting survey is a per-shaft exercise repeated three times, not one walk of the
building.

A display that cannot hear anything is not silent: it greys out and turns its
RGB LED amber after 180 s without a STATS packet (spec 6). That is how you find
a bad mounting position - walk each shaft's landings and look at the LEDs.

Power draw is small enough that a 1 A adapter is generous, and the LDR on
GPIO34 handles night dimming on its own, so the board does not need to be
positioned for a light switch.

---

## 8. Pre-power-on checklist

Run this on **each** transmitter with the pack **disconnected**, before it is
ever connected. Each line is here because getting it wrong costs a board. Three
transmitters means running it three times; it is not a checklist you pass once
for the design.

| # | check | how | pass looks like |
|---|---|---|---|
| 1 | No shorts on the pack rail | meter in continuity/resistance across the spade pair, pack off | not a short. You should read roughly the divider's 120 kΩ in parallel with whatever the buck input looks like. A beep here means stop. |
| 2 | Polarity, pack to buck | trace IN+ to pack positive and IN− to pack negative by eye and by meter | the buck's silkscreen agrees with the wires |
| 3 | Ground is one node | continuity: XIAO GND to buck OUT− to divider bottom leg to pack minus | all four beep together |
| 4 | **Buck output is 5 V** | section 3.4, with the output disconnected from everything | 5.0 V on the meter, checked after a power cycle |
| 5 | Buck output polarity | OUT+ goes to the **5V** pad, not 3V3, not any signal pad | read the silkscreen twice |
| 6 | Divider ratio is sane | meter R1 and R2 in circuit: ~100 kΩ top, ~20 kΩ bottom | ratio near 6.0. If R1 and R2 got swapped the pin sees 5/6 of the pack - over 10 V straight onto a 3.3 V pin. |
| 7 | Divider tap goes to D0 | continuity from the R1/R2 junction to the D0 pad | beeps, and does **not** beep to D1, 3V3 or GND |
| 8 | Nothing on D4/D5 but the BMP390 | visual | SDA to D4, SCL to D5, not crossed |
| 9 | Antenna attached | visual | screwed down before any power |
| 10 | **USB unplugged** | visual | see section 3.5 |
| 11 | **This is the right shaft's firmware** | the startup banner's `[tx] txId='B' (0x42) @ 915.0 MHz` line names the elevator letter and the LoRa frequency it was built for. A car node prints no mesh channel - it has no ESP-NOW radio in its build (`tx_base` leaves `espnow_mesh.cpp` out) | the letter matches the car this node is about to go into, and the frequency is that shaft's - 913.0 for A, 915.0 for B, 917.0 for C |

Then, in order:

1. Connect the pack at the spade terminals.
2. Meter the XIAO 5V pad against GND with the node running. Still 5 V. The
   3V3 pad, now an output, should read 3.3 V.
3. Check the serial console: the BMP390 should come up (and say which address
   it found), and `batteryBegin()` prints the divider and calibration
   configuration it was compiled with.
4. Meter the pack at the terminals and compare with what the node reports. If
   the two disagree by more than a few percent, go back to check 6 before
   reaching for section 4 - a calibration ratio will happily paper over a
   wrong resistor and leave you with a reading that is right at one voltage and
   wrong everywhere else.

Only when all of that passes does the node go in the car - and only into the car
whose letter check 11 printed.

### 8.1 Before any board goes on a wall

The bridges and the displays have no pack, no divider and no buck, so none of the
checks above apply to them. They have exactly one failure mode worth a checklist,
and it is the one that does not announce itself.

| # | check | how | pass looks like |
|---|---|---|---|
| 1 | The board in your hand carries a shaft label | visual, on the board itself | a letter, written at the programmer (sections 6 and 7) |
| 2 | That letter is the shaft you are standing in | visual | they match. An unlabelled board goes back to the bench, not on the wall - there is no way to read a CYD's build from its case |
| 3 | For a display, the landing exists in that shaft's table | visual | a board going onto a basement landing belongs to A or C; B has no basement |
| 4 | The shaft has exactly one bridge | count | two bridges on one channel collide in the `origSeq` space, which the bridge console warns about but nobody is watching |

Then let the car run normally for a while and walk the landings: every screen in
the shaft should show a floor rather than CHECK SHAFT - and CHECK SHAFT here
means the car, not the board in front of you, because it appears on the whole
shaft at once or not at all (section 7). A single screen still on the splash
while its neighbours show floors is the mis-flash case instead. That is the acceptance
test for the whole shaft, and it is deliberately read off the screens rather than
off a console - during a commissioning run the car is on its pack, and section
3.5 forbids a USB cable anywhere near the transmitter while it is. `FLASHING.md`
has the procedure and what each screen state means.

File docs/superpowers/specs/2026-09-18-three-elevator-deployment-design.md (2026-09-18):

# Three elevators: A, B and C

Deploying this system across three shafts instead of one, where two of them
have a basement.

The guiding constraint: **elevator B must behave exactly as the single-elevator
system does today.** Every change here is either a per-elevator build flag or a
new state that only appears when something is misconfigured. There is no change
to either wire format, no change to the algorithm, and no change to the normal
operating UI.

---

## 1. What is actually being deployed

| | elevator A | elevator B | elevator C |
|---|---|---|---|
| landings | B, 1-10 | 1-10 | B, 1-10 |
| landing count | 11 | 10 | 11 |
| transmitters | 1 | 1 | 1 |
| bridges | 1 | 1 | 1 |
| displays | 11 | 10 | 11 |

Three transmitters, three bridges, 32 displays. The three shafts are far apart
in the building, but far apart is not a guarantee - LoRa at 22 dBm carries a
long way indoors, and ESP-NOW on the 802.11 LR PHY is more sensitive than
ordinary WiFi. The design assumes all three systems can hear each other and
makes that harmless, rather than assuming they cannot and finding out later.

---

## 2. The frequency and channel plan

| | elevator A | elevator B | elevator C |
|---|---|---|---|
| `LORA_FREQUENCY` | 913.0 MHz | **915.0 MHz** (unchanged) | 917.0 MHz |
| `MESH_CHANNEL` | 6 | **1** (unchanged) | 11 |
| `ELEV_TX_ID` | `0x41` `'A'` | `0x42` `'B'` | `0x43` `'C'` |
| `FLOOR_LABEL_COUNT` | 11 | **10** (unchanged) | 11 |
| `FLOOR_LABELS` | `B,1..10` | **`1..10`** (unchanged) | `B,1..10` |

Everything else - spreading factor, bandwidth, coding rate, sync word, TX power,
preamble, hop limit, repeats, jitter, dedup depth - is identical on all three
systems and unchanged from today.

### 2.1 Why the LoRa link needs separate frequencies

Three cars on one frequency is pure ALOHA with no carrier sense. A STATE packet
is 297 ms and goes out every 2 s while the stream is active. The right duty
figure is **0.90, the STATE-active fraction, not the 0.712 moving fraction** -
the 2026-09-11 spec §2.2 makes this correction in bold, and for the same reason
it matters here: STATE is not gated on motion, it runs for
`STATE_HOLD_AFTER_STOP_MS` (10 s) past every stop, and those packets are the
same 297 ms at the same 22 dBm and collide identically. So each car offers
`0.5 x 0.90 = 0.45` packets per second. ALOHA's vulnerable window is two packet
lengths, `2 x 0.297 = 0.594 s`, so the probability a given STATE packet survives
two interferers is

```
P(survive) = exp(-2 x 0.45 x 0.594) = exp(-0.5346) = 0.586
```

**About two STATE packets in five are lost**, on top of the 5.21% the shaft
already costs (`ALGORITHM.md` §9), and concentrated in exactly the evening peak
when all three cars are busy simultaneously. That is not a degradation the
display's staleness logic is designed to absorb.

(`exp(-2G)` assumes Poisson arrivals and STATE is a periodic 0.5 Hz stream, so
this is an estimate rather than a prediction. It does not need to be better than
that: both the figure above and the one the moving fraction would give are
decisively against sharing a frequency, which is the only decision it informs.)

**A per-elevator sync word does not fix this and must not be mistaken for a
fix.** The sync word is checked after preamble detection and demodulation; it
filters frames that were already received successfully. It does nothing to stop
two 22 dBm carriers from destroying each other in the air. Frequency separation
is the only mechanism here that prevents collisions rather than merely
classifying the wreckage.

2 MHz of separation against a 125 kHz occupied bandwidth is roughly 16 channel
widths. That margin is chosen against the near-far case - a transmitter in one
shaft at close range to another shaft's bridge - not against the typical case,
where the shafts are far apart anyway. 913.0 / 915.0 / 917.0 all sit inside the
902-928 MHz ISM band with wide margin to both edges, and the modulation,
occupied bandwidth and duty cycle are unchanged from the single-elevator
deployment, so nothing about the regulatory picture changes.

The sync word stays 0x34 on all three. Changing it would buy nothing real and
is one more per-elevator value to get wrong.

### 2.2 Why the ESP-NOW meshes are separated by channel

No display ever needs another shaft's data. Isolating the three floods on
channels 1, 6 and 11 means **each mesh is exactly the ten-node, single-origin
system that was already measured and tuned**, so every number in `MESH.md`
remains valid as written.

The alternative - one building-wide flood carrying elevator-tagged frames -
creates two problems that would then have to be solved:

1. **`origSeq` collides.** Three bridges each mint a monotonic u16 into one
   flood. Bridge A's frame 4113 and bridge C's frame 4113 are indistinguishable
   to `meshDedupSeenOrInsert()`, which tests equality against a ring of recent
   values with no notion of who minted them. The second one is dropped as a
   duplicate. Not once - continuously, at random, forever. Fixing it means an
   origin field in the envelope and a `MESH_VERSION` bump.
2. **The relay jitter stops working.** `MESH_REPEATS` is 3 and the jitter window
   is 5-40 ms. With 32 displays and 3 bridges, a single frame reaching every
   node produces around 96 transmissions contending for a 35 ms window, each
   about 1.3 ms long - roughly 3.5x oversubscribed. `MESH.md` §5 is explicit
   that the jitter window existing at all is the difference between a mesh that
   works and one that does not; oversubscribing it re-creates precisely the
   collision it was introduced to prevent.

Channel isolation makes both problems not exist, rather than patching them. It
costs nothing that is wanted: the only thing given up is cross-shaft path
diversity, which is worthless when the shafts are far apart.

A side benefit worth recording: because `MESH_CHANNEL` is per-elevator, any one
shaft can be moved to a different channel independently if a site survey finds
its channel congested (`MESH.md` §11). The only rule is that two shafts within
earshot must not share a channel.

### 2.3 Why the mesh needs no elevator field

Adding an elevator id to the mesh envelope was considered and rejected. With the
floods on separate channels, a display physically cannot receive another shaft's
frames, so the field would never discriminate anything at runtime.

The same fact disposes of the failure it would have guarded. A display flashed
for the wrong shaft is not shown the wrong car - it is **deaf**. It sits on a
channel its landing's bridge does not transmit on, hears nothing at all, and
stays on the boot splash. That is the loudest failure available: a screen that
never comes up is noticed on the day it is installed, which is exactly when
somebody is standing in front of it. An elevator field in the envelope would be
one byte spent to detect a condition in which no bytes arrive.

`MESH_VERSION` therefore stays 1, `MESH_MAGIC` stays 0x5E1E, and the envelope is
byte-for-byte what is deployed today.

---

## 3. `txId`, and the bridge's foreign-packet filter

`txId` has been in both LoRa formats since the beginning, reserved for exactly
this. It is now meaningful: `'A'`, `'B'` or `'C'` as ASCII, so that a hex dump
reads `E0 42 ...` and identifies the shaft without a lookup table. That choice
is for the benefit of someone decoding a capture in a stairwell, which is the
audience `PROTOCOL.md` is written for.

`bridge_rx.cpp` does not look at `txId` today - `handleFrame()` checks the tag,
dispatches on it, and wraps whatever arrives. It gains one check: a packet whose
`txId` is not this bridge's elevator is dropped and counted in a new
`dropForeignTxId` counter, alongside the existing `dropTagCount` and
`dropLenCount`.

With 2 MHz of separation that counter should read 0 forever. **That is the
point.** A non-zero value is unambiguous evidence of cross-shaft leakage rather
than an inference from a loss statistic, and it is the pass condition for the
bench test in §7.2.

The bridge continues to strip `txId` before wrapping, exactly as
`meshWrapLora()` does today. Displays still never see it. Nothing downstream of
the bridge changes.

### 3.1 The pre-existing foreign-origin warning

`bridge_rx.cpp:295` already warns when it hears a mesh frame on its channel that
it did not mint, with the text *"a second origin on channel N would collide in
the origSeq space"*. That guard was written for the single-elevator system and
happens to be exactly the instrument that detects two bridges accidentally
sharing a channel. It needs no change, but it does need documenting as a
deliberate part of the three-elevator verification story.

---

## 4. The basement, and the commissioning readout

This is the part that is a correctness problem rather than a configuration
problem, and it deserves the most care.

### 4.1 The failure

`floor` index 1 is defined as *the lowest landing ever seen*, not as a name. The
model is learned at runtime from confirmed stops. If elevator A is commissioned
over a period in which nobody presses B, the model learns a span of 10 landings,
sets `modelReady`, and starts broadcasting confident floor indices 1-10 - which
the display maps onto labels `B,1,2,...,9`.

**Every label on all eleven of A's displays is then one floor too low,
indefinitely, and looks entirely plausible.**

Nothing inside the algorithm can detect this. `anchorStep()` exists to resolve an
unknown *offset* after an NVS restore, and it locks when the span of indices seen
since boot equals the learned span (`floor_monitor.h:879-900`). In this failure
the learned span is 10 and the seen span is 10; they agree. The model is
internally consistent and wrong.

The only thing in the system that knows the building has eleven landings is
`FLOOR_LABEL_COUNT` on the display. So the check must live there.

### 4.2 Why the check cannot live on a console

The obvious commissioning step - read `nFloors` off a serial console - is
unusable in this building:

- **The bridge console is unreachable in practice.** It is a wall-powered box
  mid-shaft. Reading it means standing at it with a laptop, but the answer is
  only known after a full end-to-end run, by which time the person is elsewhere.
- **The transmitter console is forbidden.** `HARDWARE.md` §3.5 requires that USB
  is never plugged in while the buck is feeding the XIAO's 5V pad. A
  commissioning run happens with the car on battery, which is precisely the
  condition under which no USB cable may be attached.

During the exact procedure that needs verifying, there is no serial port
anywhere in the system. The displays are the only instrument available, so the
verdict has to be rendered on them.

### 4.3 The four states, from fields already on the wire

`elevator_tx.cpp:270` sends `floor = 0` whenever `modelReady` is clear, and
`floor_monitor.h:1032` sets `b.modelReady = modelReady() && !positionUnknown_` -
so the learning case and the post-restore anchoring case are indistinguishable
from STATE alone. `ELEV_FLAG_NVS_RESTORED` in STATS separates them, which is the
"restored and trusted versus learned here" distinction `PROTOCOL.md` §3 already
describes that flag as existing for.

| `nFloors` | `MODEL_READY` | `NVS_RESTORED` | screen |
|---|---|---|---|
| `< labelCount` | 0 | 0 | **LEARNING** - big digits show `nFloors`, the word `LEARNING` and `OF 11` beneath |
| `== labelCount` | 0 | 1 | **ANCHORING** - words, not digits: ride to both ends |
| `== labelCount` | 1 | - | normal operation |
| `!= labelCount` | 1 | - | **CHECK SHAFT** - the off-by-one trap |

No wire change. No new flag. No reserved bit spent.

**All three inputs must be taken from STATS.** `MODEL_READY` is also in STATE,
and reading it from there is wrong in a way that is not obvious: STATE only runs
while the car moves plus a 10 s hold, so on a display that booted into a parked
shaft it is false because nothing has arrived, not because the car said
anything. Combined with an `nFloors` that did arrive, that reads as "full span,
not ready" - ANCHORING - so every screen in a healthy parked shaft would ask to
be ridden to both ends after any display reset. One packet, one snapshot.

The last row is the one that matters: a model that is ready and confident but
reports a floor count the building does not have. **It has exactly one cause** -
a car that has never reached its lowest landing - and it necessarily appears on
every screen in the shaft at once, because every display in a shaft carries the
same label table and hears the same bridge.

A display carrying the wrong shaft's label table is *not* a second cause, though
it looks like one. Such a display is on the wrong mesh channel too, so it hears
nothing and renders nothing (§2.3). CHECK SHAFT on one screen out of eleven is
not a diagnosis to plan for - it cannot happen.

### 4.4 What the count readout is, and is not

`nFloors()` is `maxIndex() - minIndex() + 1` (`floor_monitor.h:530`) - **the span
of learned indices, not a tally of landings visited.** Two consequences the
documentation must state plainly, because the obvious reading is wrong:

- **It is not a progress bar.** An express run from the basement to floor 10
  produces indices 1 and 11 and the readout jumps straight from 2 to 11. It will
  not tick 3, 4, 5.
- **It is only meaningful once pitch is established**, which needs ordinary
  multi-stop traffic rather than one long run.
- **It must not be shown as a bare number.** The learned span of a shaft being
  commissioned runs 2..11, which is exactly the range of real floor labels, and
  it is drawn in the same seven-segment glyphs the floor number uses. Without
  the word `LEARNING` at a size that survives corridor distance, a passer-by
  reads the count as the floor the car is on. The `OF 11` caption does not
  carry that on its own - it is the first thing to stop resolving as you walk
  away.

So the commissioning instruction is *"let the car run normally for a while, then
check that every screen in the shaft shows a floor rather than CHECK SHAFT"* -
not *"watch it count up"*.

### 4.5 Order does not matter

Bottom-then-top and top-then-bottom are the same operation.
`floor_monitor.h:888` already says so for the restore case: *"ride to the bottom
floor and the top floor, in either order."* For the fresh-learn case the span
grows regardless of direction. Neither the procedure nor the code prefers a
direction, and the documentation should say so explicitly so that nobody invents
a ritual.

### 4.6 `--` does not go away

`--` remains correct for "frames are arriving but there is no confirmed floor",
which is a different condition from all four states above and must not be given
a number.

A display that has heard *nothing* since boot is a third thing again, and it
does not show `--` either: `floor_display.cpp` only calls `displayUpdate()` once
a frame has arrived, so until then the boot splash stays on the glass. Three
conditions, three appearances - splash for "nothing has ever arrived", `--` for
"arriving, no floor yet", and the commissioning screens for "arriving, and the
model and the building disagree".

### 4.7 Rendering the basement label

No rendering change is needed. `segmentsFor()` in `display_ui.cpp:97` already has
a seven-segment glyph for `'B'`, and `DISPLAY_MAX_LABELS` is 32, so an
eleven-entry label table fits with room to spare. This was verified by reading
the code, not assumed.

---

## 5. Code changes

Deliberately small. Every item is either a build flag or a new state that only
appears when something is misconfigured.

### 5.1 `platformio.ini`

Three new per-elevator sections holding four values each:

```ini
[elev_a]
build_flags = -DLORA_FREQUENCY=913.0f -DMESH_CHANNEL=6 -DELEV_TX_ID=0x41
[elev_b]
build_flags = -DLORA_FREQUENCY=915.0f -DMESH_CHANNEL=1 -DELEV_TX_ID=0x42
[elev_c]
build_flags = -DLORA_FREQUENCY=917.0f -DMESH_CHANNEL=11 -DELEV_TX_ID=0x43
```

`LORA_FREQUENCY` and `MESH_CHANNEL` are already defined in `[lora_base]` and
`[mesh_base]`. The per-elevator value must win. Since both are consumed through
`#ifndef` guards in `lora_link.h` and `espnow_mesh.h`, a duplicate `-D` on the
command line is a redefinition warning at best and a silent wrong value at
worst. **The base sections must stop defining the per-elevator values entirely**,
so that each value is defined in exactly one place, and a missing elevator
section is a compile error rather than a silent fallback to B's numbers.

Nine firmware environments: `elevator_tx_{a,b,c}`, `bridge_rx_{a,b,c}`,
`floor_display_{a,b,c}`. `default_envs` lists all nine. `native` and `sim` are
unchanged.

The label flags move from `[env:floor_display]` into the per-elevator display
envs: A and C get `FLOOR_LABEL_COUNT=11` and `FLOOR_LABELS="B,1,...,10"`, B keeps
10 and `1,...,10`.

### 5.2 `src/bridge_rx.cpp`

- `dropForeignTxId` counter next to `dropTagCount` / `dropLenCount`.
- In `handleFrame()`, after the tag check and before dispatch: read `txId` at
  `ELEV_OFF_TXID` and drop if it is not `ELEV_TX_ID`, logging the offending
  value and the RSSI in the same style as the unknown-tag path.
- The counter appears in `printSummary()`.
- The startup banner prints which elevator, frequency and channel this build is
  for, so a console session immediately reveals a mis-flashed bridge.

### 5.3 `src/display_ui.h` / `src/display_ui.cpp`

- `DisplayUiState` gains `uint8_t modelFloors` and `bool modelFloorsValid`.
- A commissioning state enum derived from those plus the existing `modelReady`
  and an `nvsRestored` flag that must also be plumbed through.
- Rendering for LEARNING (count in the big digits, `OF n` beneath), ANCHORING
  (text) and CHECK SHAFT (text), reusing the existing centred-message path
  rather than inventing a new layout.

### 5.4 `src/floor_display.cpp`

- `applyStats()` already unpacks `nFloors` and `flags` and throws both away
  after a `Serial.printf`. Capture `s.nFloors`, `elevStatsNvsRestored(&s)` and
  `elevStatsModelReady(&s)` into statics.
- `buildUiState()` populates the new fields. Note that `modelReady` for the
  commissioning decision is the STATS copy, while `positionValid` keeps using
  the STATE copy - see §4.3 for why crossing the two breaks a parked shaft.
  These are two different questions: "may this node animate right now" follows
  STATE, "what did the car last say about its model" follows the heartbeat.
- The startup banner names the elevator this build is for.

### 5.5 `src/elevator_tx.cpp`

- `ELEV_TX_ID` loses its `#define ELEV_TX_ID 1` fallback at line 86-87, so that
  building a transmitter without an elevator selected fails loudly.
- The startup banner already prints `txId`; it should print it as a character.

### 5.6 Tests (`test/`)

New host-side coverage, run by `pio test -e native`:

- an eleven-entry label table parses, and index 1 is `B`
- the four commissioning states are selected correctly from every relevant
  combination of `nFloors`, `modelReady` and `nvsRestored`
- a `txId` that is not this elevator's is rejected; one that is, is accepted
- `'B'` has a non-zero seven-segment glyph

---

## 6. Documentation changes

| file | change |
|---|---|
| `README.md` | three elevators, the deployment table, the per-shaft radio plan |
| `docs/PROTOCOL.md` | §1 gains the frequency plan; `txId` is no longer "only one car exists"; a new section on the three-system collision analysis and why sync words are not the answer |
| `docs/MESH.md` | the channel plan and the isolation argument; why not one flood; the `origSeq` and jitter arithmetic from §2.2; §11's survey becomes per-shaft |
| `docs/FLASHING.md` | nine environments, the which-image-on-which-board table, board labelling, the commissioning procedure, the four screen states, the bench coexistence test |
| `docs/HARDWARE.md` | 3x parts, per-shaft bridge placement, eleven-landing shafts |
| `docs/ALGORITHM_PORT.md` | untouched - the algorithm does not change |

---

## 7. Verification

### 7.1 Every link, and why it does not collide

The table the documentation must carry, one mechanism per row:

| communication | competes with | isolation mechanism | observable |
|---|---|---|---|
| car X -> bridge X (LoRa) | cars Y, Z | 2 MHz frequency separation | bridge loss statistics |
| car Y -> bridge X (LoRa) | - | frequency, then `txId` filter | `dropForeignTxId` (bench) |
| bridge X -> displays X (ESP-NOW) | bridges Y, Z | separate channels 1/6/11 | `foreignOrigins` (bench) |
| display <-> display within X | its own shaft | unchanged jitter and dedup | `MeshCounters` |
| mesh X | building WiFi on that channel | per-shaft site survey | `MESH.md` §11 procedure |
| LoRa (915 MHz) | ESP-NOW (2.4 GHz) | different band | none needed |

### 7.2 Bench coexistence test

All three transmitters and all three bridges powered at once, on a bench, with
laptops attached.

**Keep every board at least 1 m from every other board.** This is a minimum, not
a maximum, and it is a hardware limit rather than a matter of taste. The
SX1262's absolute maximum RF input is about +10 dBm (`HARDWARE.md` §3.1) and the
transmitters run at 22 dBm, so in free space at 915 MHz:

```
  0.10 m  ->  +10.3 dBm    over the absolute maximum
  0.25 m  ->   +2.4 dBm
  0.50 m  ->   -3.6 dBm
  1.00 m  ->   -9.7 dBm    about 20 dB of margin
```

The crossover is 10.4 cm. Six boards "on one table" is exactly how two of them
end up 5 cm apart, and the damage is to a receiver front end rather than to the
test.

**What this proves, and what it does not.** Equidistant boards are a near-far
ratio of zero, so this is not the worst case - it is the case where every
foreign signal arrives at the *same* power as the wanted one. That is a real
stress on adjacent-channel rejection, and far harsher than the typical building
geometry where a foreign car is much further away than your own. But the genuine
worst case - a foreign car a metre from your bridge while your own car is ten
floors up the shaft - is not reproducible on a bench, and this test should not
be described as though it were.

Pass conditions:

- each bridge's `publishCount` advances at its own car's cadence
- each bridge's `dropForeignTxId` stays at 0
- **no** `foreignOrigins` field appears in any bridge's summary line -
  `printSummary()` prints that counter only when it is non-zero, so the pass
  condition is its absence, not a printed zero
- no bridge's loss statistics degrade when the other two are powered versus when
  they are not

This is where `dropForeignTxId` earns its place, because a laptop is attached.

### 7.3 Instrument honesty

**`dropForeignTxId` and `foreignOrigins` are bench instruments, not field
instruments.** Both live in the bridge console, which §4.2 establishes is
unreachable during normal operation. The documentation must say so rather than
implying field visibility that does not exist. In the field, the argument for
non-interference is the frequency and channel separation, plus the fact that a
filtered foreign packet degrades to silence rather than to a wrong floor.

The field instruments are the displays: §4.3's four states.

### 7.4 Build and test verification

- `pio test -e native` - all existing tests plus §5.6, on the host
- `pio run` - all nine firmware environments compile
- a check that the nine environments actually differ: extract
  `LORA_FREQUENCY`, `MESH_CHANNEL`, `ELEV_TX_ID` and `FLOOR_LABEL_COUNT` from
  each built environment and confirm they match the table in §2. A build matrix
  that silently collapses to three identical images is the most likely way this
  change goes wrong, and it is invisible in a passing build.

---

## 8. What is deliberately not being done

- **No mesh envelope change.** No elevator field, no `MESH_VERSION` bump. §2.3.
- **No LoRa format change.** Both formats are byte-identical to today.
- **No per-elevator sync word.** §2.1 - it does not prevent collisions.
- **No shared display showing all three cars.** One display per elevator per
  floor, so the existing single-car UI is unchanged.
- **No runtime elevator selection.** Identity is a build flag. The mitigation
  for a mis-flashed board is §4.3's CHECK SHAFT state plus physical labelling,
  not a touch-screen picker.
- **No anchoring progress on the wire.** The seen-span is not transmitted and
  will not be. Spending a reserved `state` bit on a condition that resolves
  itself in one round trip is not worth the wire surface.

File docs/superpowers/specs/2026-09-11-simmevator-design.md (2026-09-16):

# Simmevator — elevator floor tracker and per-floor displays

Design spec. Simmons Hall, MIT.

A barometer in the elevator car decides which floor the car is on and broadcasts
it over LoRa to a bridge on floor 5, which floods it over ESP-NOW to a display on
every floor. The car node runs on a battery for at least a month.

The floor-detection algorithm is not designed here. It exists, it is measured, and
it is specified in `../../../../elevatormons/docs/ALGORITHM.md` with a reference
implementation in `elevatormons/tools/floor_algorithm.py`. This spec covers
porting it faithfully to C++ and building a system around it. **The algorithm's
tuning constants are not to be re-tuned.**

---

## 1. Why the system is shaped this way

Three constraints drive every decision below.

**The floor decision must happen in the car.** ALGORITHM.md §9: the node holds the
sensor, so it sees an unbroken 1 Hz stream. Radio loss can only age what a display
shows — it can never corrupt the floor, and one received packet resyncs
everything. Moving the decision to the bridge would make every dropout a
correctness problem instead of a latency problem.

**Absolute altitude cannot decide the floor.** Over the 3 h reference capture the
sea-level reference wandered 9.9 m — more than three floor heights. Floors are
read from *jumps between stops*, which are short enough that weather cannot move
them. This is why there is a learned building model and why it is worth
persisting.

**Airtime is the power budget.** At SF10 a LoRa packet costs hundreds of
milliseconds at ~118 mA. The transmit schedule, not the sleep current, is what
decides whether the battery lasts a month.

---

## 2. Power budget

Battery: LiFePO4 4S, 12.8 V nominal, 10 Ah = 128 Wh. Through a buck module at
~85% into 5 V, then the XIAO's onboard SGM6029 synchronous buck down to 3.3 V
(~85-90% at these loads), that is ≈29 Ah at 3.3 V. For 30 days (720 h) the
average draw must stay under **40 mA**.

The 5V pad is fed rather than the 3V3 pad because 3V3 is that regulator's
output, not an input. The second conversion costs ~10%, not the third a linear
part would have cost. §3.3 has the trade.

### 2.1 Radio configuration

ALGORITHM.md §9 records the field run as `SF10 / BW125 / 14 dBm` → 5.21% batch
loss over 3 h. `elevatormons/platformio.ini` sets `baro_base` to BW62.5, which has
no in-shaft evidence. **This project uses BW125** — the configuration that was
actually measured — at 22 dBm, which is 8 dB more margin than the run that
produced that 5.21% figure.

| config | 8-byte airtime | sensitivity | in-shaft evidence |
|---|---|---|---|
| SF10/BW62.5/CR4-8 | 725 ms | −135 dBm | none |
| **SF10/BW125/CR4-8** | **297 ms** | −132 dBm | 5.21% loss at 14 dBm |

§9 also records that loss barely tracks SNR (r = −0.13) — it is shadowing and
interference, not a decode floor — so buying margin with spreading factor buys
little while costing airtime linearly.

Airtime derivation (SF10, BW125 kHz, CR 4/8, explicit header, LDRO off since
Ts = 8.192 ms < 16 ms):

```
Ts       = 2^10 / 125000          = 8.192 ms
preamble = (8 + 4.25) * Ts        = 100.4 ms
nPayload = 8 + ceil((8*PL - 4*SF + 28 + 16) / (4*SF)) * 8
PL =  8 -> 8 + ceil(68/40)*8  = 24 sym -> 196.6 ms -> total  297 ms
PL = 24 -> 8 + ceil(196/40)*8 = 48 sym -> 393.2 ms -> total  494 ms
```

### 2.2 Transmit schedule

Measured from the reference capture, the car is "moving" (by the algorithm's own
stillness test) **71.2% of an evening peak**. Over a full day including nights it
is far lower, but the budget below uses the peak figure.

| mode | trigger | cadence |
|---|---|---|
| STATE | car moving, or within 10 s of a stop | every 2 s, first packet fires immediately on motion onset |
| STATS | always | every 60 s |

The **STATE-active fraction is 0.90, not the 0.712 moving fraction.** The stream
runs for `STATE_HOLD_AFTER_STOP_MS` = 10 s past every stop, which the trigger
column above says and an earlier version of this table forgot. The hold is
deliberate — a display should not go stale the instant the doors open, and the
car frequently moves again within those 10 s — but it is airtime and it has to
be paid for here.

| line item | current |
|---|---|
| XIAO light-sleeping between samples | ~3 mA |
| STATE: 297 ms / 2 s × 140 mA × **0.90 active** | ~18.7 mA |
| STATS: 494 ms / 60 s × 140 mA | ~1.2 mA |
| divider + BMP390 | ~0.1 mA |
| **total at evening-peak traffic** | **~23 mA → ~50 days** |

140 mA is the SX1262 at +22 dBm (~118 mA) plus the ESP32-S3 awake **at 80 MHz**.
That clock is not the board default — `TX_CPU_MHZ` pins it, because RadioLib
busy-polls DIO1 for the whole 297 ms of every packet, so whatever the core is
clocked at is spent for the entire airtime. At the default 240 MHz the core term
roughly doubles and this table is wrong by ~8 mA. Deep sleep is impossible: the
algorithm needs an unbroken 1 Hz stream. Light sleep between samples is what
makes the baseline 3 mA instead of ~25 mA.

50 days still clears the one-month requirement, with ~1.7× margin at the *peak*
traffic rate — a real week including nights does better. The 56 days this table
showed when the 3.3 V rail was fed directly, and the 68 days an earlier version
claimed, should not be quoted.

### 2.3 What is arithmetic and what is measured

Everything above is **calculated, not measured.** No board has been on a meter.
Three line items could each move the total and are not in the table because
nobody knows their size yet:

| unknown | why it is not costed |
|---|---|
| real light-sleep floor on a XIAO | the ~3 mA is the datasheet part. The board also carries a power LED and a charge IC. This is the least trustworthy number in the budget. |
| PSRAM left initialised | `[env:elevator_tx]` inherits `BOARD_HAS_PSRAM`; the core powers 8 MB that nothing allocates from. Disabling it means fighting the prebuilt core's `CONFIG_SPIRAM`. |
| USB-Serial-JTAG PHY | `Serial.begin()` powers the pad and nothing calls `Serial.end()`, so it stays up for the whole deployment. |
| ADC analog block | `batteryBegin()`'s throwaway conversion creates a oneshot unit that is never released, holding the SAR block powered rather than only for 32 samples a minute. |

The first hardware session should put a meter on the 3.3 V rail for an hour
before anyone trusts the day count. If the floor comes back at 8 mA rather than
3, the month still holds and the 50 days does not.

If measured life falls short, the knobs in order of preference are: STATE cadence
2 s → 3 s (−5 mA), TX power 22 → 20 dBm (−2 mA), parked heartbeat 60 s → 120 s
(−0.6 mA).

---

## 3. Hardware

### 3.1 Transmitter — in the car, on battery

Seeed XIAO ESP32S3 + Wio-SX1262 (a stack, no wiring) + BMP390 on I²C bus 1.

| signal | pin | note |
|---|---|---|
| BMP390 SDA / SCL | D4 = GPIO5 / D5 = GPIO6 | `Wire1`, 400 kHz, addr 0x77 |
| SX1262 SCK/MISO/MOSI | D8/D9/D10 = GPIO7/8/9 | via the expansion stack |
| SX1262 NSS/DIO1/BUSY/NRST | GPIO41/39/40/42 | |
| **battery sense** | **D0 = GPIO1 (ADC1_CH0)** | see below |

D0 is the only free ADC1 pad — D4/D5 are I²C, D8/D9/D10 are SPI, and GPIO39–42
belong to the radio.

### 3.2 Battery sense divider

```
  BATT+ ──[ R1 = 100 kΩ 1% ]──┬── D0 (GPIO1)
                            │
                       [ R2 = 20 kΩ 1% ]
                            │
  BATT− ──────────────────── ┴── GND (common with XIAO GND)
```

Ratio 6.0. 14.6 V → 2.433 V; 10.0 V → 1.667 V. The whole span sits in the
ESP32-S3 ADC's linear region at 12 dB attenuation, which misbehaves below ~0.15 V
and above ~2.8 V. Divider draw is ~122 µA at 14.6 V — about 0.5% of the budget, so no switching
MOSFET. The resistances are kilohms rather than megohms because there is no
filter capacitor: the ADC's sample capacitor charges through the divider's
Thevenin resistance (~16.7 kΩ here, ~167 kΩ with 1 MΩ / 200 kΩ), and the lower
value lets each sample settle.

There is no filter capacitor across R2. The 12 V rail moves on a timescale of
hours and the reading is taken once a minute, so the noise this leaves is
rejected in software instead: oversample 32 times and take the median rather than
the mean, which also discards the occasional outlier sample the S3's SAR ADC
produces. Read with `analogReadMilliVolts()` (applies the factory eFuse
calibration), once per STATS packet. A one-point correction
`-DVBAT_CAL_NUM` / `-DVBAT_CAL_DEN` is set once against a DMM.

LiFePO4 4S thresholds, decided on the transmitter with a latch and carried in
the STATS flags:

| threshold | level | screens show | notice at ~23 mA |
|---|---|---|---|
| < 12.8 V | LOW, ~20% left | amber CHARGE SOON badge | ~3 days |
| < 12.0 V | CRITICAL, ~10% left | steady red CHARGE BATTERY banner, red LED | under 2 days |
| ≥ 13.3 V | clears either | normal bar | - |

An earlier version of this section called 12.0 V "~20% remaining". It is nearer
10%. The warning latches rather than following the voltage, so it cannot flicker
off by itself, and it clears only on a charged pack. It stays in colour when the
link goes stale, because a flat battery is the likeliest cause of the silence.
The thresholds sit where uncalibrated ±0.4 V matters, so calibration is needed
for the notice to be accurate.

### 3.3 Power chain

`LiFePO4 4S 10 Ah → spade terminals → MP1584EN buck at 5 V → XIAO 5V pad → the
XIAO's onboard buck → 3.3 V`.

The pack's own BMS provides the overcurrent and undervoltage protection, and the
spade terminals are what let the pack come off the buck for charging.

The 5V pad is the board's supply input; the 3V3 pad is the output of the XIAO's
onboard SGM6029 buck and is not fed. That second conversion turns ~56 days into
~50 (§2), and a 3.3 V module into the 3V3 pad would recover them at the cost of
back-driving that regulator. **Do not connect USB and the buck at the same time** — the 5V pad and
USB VBUS are the same node. Unplug the battery before flashing.

The MP1584 is PWM-only with no light-load PFM mode, so it is poor at the 3 mA
sleep current but runs ~80–85% at the ~23 mA average, which is what §2 assumes. A
TPS62203 or MP2338 would recover a few days; not required.

**The 3D-printed enclosure must be vented.** A sealed box turns the barometer
into a thermometer and the system stops working. A small hole with a scrap of
foam or filter cloth over it is enough - it needs to equalise on the timescale of
seconds, not to breathe freely.

### 3.4 Bridge — floor 5, wall powered

XIAO ESP32S3 + Wio-SX1262, USB-C 5 V. LoRa receive continuous. ALGORITHM.md §9
flags floor 9 as the one landing whose SNR crosses the decode floor — an
intermittent shadow — so bridge antenna placement should favour the upper shaft.

### 3.5 Displays — one per floor

ELEGOO ESP32 CYD 2.8", ESP32-WROOM-32, ILI9341 240×320, USB-C. Board
`esp32dev`. Pin map (the standard ESP32-2432S028R):

| function | pins |
|---|---|
| TFT SPI | MOSI 13, MISO 12, SCLK 14, CS 15, DC 2, RST −1 |
| backlight | 21 (active high, PWM) |
| touch XPT2046 | CLK 25, MOSI 32, MISO 39, CS 33, IRQ 36 |
| LDR | 34 (analog) |
| RGB LED | 4 / 16 / 17 (active low) |

TFT_eSPI is configured entirely through `build_flags` in `platformio.ini` so
nothing outside this repo is edited.

### 3.6 Parts list

**Transmitter (×1 assembly)**

| Part | Qty | Notes |
|---|---|---|
| Seeed XIAO ESP32S3 | 1 | |
| Seeed Wio-SX1262 for XIAO | 1 | stacks onto the XIAO; ships with its 915 MHz antenna |
| BMP390 breakout | 1 | Adafruit 4816 or equivalent |
| LiFePO4 12.8 V 10 Ah pack with BMS | 1 | 4S; BMS required |
| LiFePO4 charger, 14.6 V | 1 | a Li-ion or lead-acid charger will not terminate correctly |
| MP1584EN 5 V buck module | 1 | meter it at 5 V **before** connecting the XIAO |
| Resistor 100 kΩ 1% | 1 | divider top |
| Resistor 20 kΩ 1% | 1 | divider bottom |
| Spade terminal pair | 1 | so the pack can come off for charging |
| Hookup wire / JST leads | — | |

No divider filter cap (oversampled in software instead), no buck input
electrolytic (the node averages ~23 mA, so the module's own ceramics are
sufficient), and no inline fuse (the pack's BMS covers overcurrent). The
enclosure is 3D printed.

**Bridge (×1)**

| Part | Qty |
|---|---|
| Seeed XIAO ESP32S3 | 1 |
| Seeed Wio-SX1262 for XIAO | 1 |
| USB-C 5 V adapter + cable | 1 |

**Displays (×10)**

| Part | Qty | Notes |
|---|---|---|
| ELEGOO ESP32 CYD 2.8" ILI9341 240×320 | 10 | sold in 2-packs → 5 packs |
| USB-C 5 V / 1 A adapter | 10 | |
| USB-C cable | 10 | |

Mounts are 3D printed.

**Totals to buy:** 2 × XIAO ESP32S3 · 2 × Wio-SX1262 · 1 × BMP390 · 1 × battery +
charger · 1 × MP1584EN · 2 × resistors · 1 × spade pair · 10 × CYD · 11 × USB-C
supplies. Enclosure and the ten display mounts are printed.

---

## 4. Wire protocols

### 4.1 LoRa: car → bridge

Tag-byte discrimination, as `elevatormons/src/baro_packet.h` does. No application
CRC: the SX1262's hardware CRC-16 is enabled and rejects corrupt frames before
RadioLib hands them over. All multi-byte fields little-endian.

**`0xE0` STATE — 8 bytes, 297 ms**

| off | size | field | meaning |
|---|---|---|---|
| 0 | u8 | `tag` | 0xE0 |
| 1 | u8 | `txId` | transmitter identity |
| 2 | u8 | `seq` | wraps; for loss statistics only |
| 3 | u8 | `floor` | confirmed 1-based index; 0 = model not ready |
| 4 | i16 | `posQ8` | live fractional position in 1/256 floor units, relative to floor 1 |
| 6 | u8 | `state` | bit0 moving · bits1-2 direction (0 idle, 1 up, 2 down) · bit3 modelReady · bit4 sensorErr |
| 7 | u8 | `confidence` | 0–255, from the lattice fit in `_arrive()` |

`posQ8` is what lets a display animate the car climbing through floors. It is
derived from the drift-tracked datum, which ALGORITHM.md §6 shows is unreliable
for *deciding* a floor — so it is used only for animation and is always corrected
by `floor` on arrival.

**`0xE1` STATS — 24 bytes, 494 ms**

| off | size | field | units |
|---|---|---|---|
| 0 | u8 | `tag` | 0xE1 |
| 1 | u8 | `txId` | |
| 2 | u8 | `seq` | |
| 3 | u16 | `batteryMv` | mV |
| 5 | u16 | `dist24hM` | metres in the last 24 h |
| 7 | u32 | `distTotalM` | metres, lifetime |
| 11 | u16 | `pitchMm` | learned floor pitch |
| 13 | u8 | `nFloors` | learned floor count |
| 14 | u16 | `trips` | |
| 16 | u16 | `stops` | |
| 18 | u32 | `uptimeS` | |
| 22 | u8 | `flags` | bit0 sensorErr · bit1 modelReady · bit2 nvsRestored · bit3 lowBattery |
| 23 | i8 | `tempC` | |

### 4.2 ESP-NOW: bridge → displays → displays

```
off  size  field
0    u16   magic     0x5E1E
2    u8    version   1
3    u8    hop       remaining hops; dropped at 0
4    u16   origSeq   monotonic, minted by the bridge
6    u8    type      0xE0 or 0xE1
7    u8    len       payload length
8..  ...   payload   the LoRa packet body from offset 3 onward
+2   u16   crc16     CCITT over everything before it
```

`origSeq` is minted by the bridge and is u16 monotonic — the LoRa `seq` is u8 and
wraps far too fast to dedup on.

**Flood rules**, identical on the bridge and all ten displays:

- Keep a 32-deep ring of seen `origSeq`. Rebroadcast each new value exactly once.
- Hop limit 8. Five floors is the furthest any display is from the bridge, so 8
  leaves slack for a detour around a dead node.
- **Wait a random 5–40 ms before relaying.** Ten displays hearing the same frame
  and relaying at once is a guaranteed collision; the jitter is the difference
  between a mesh that works and one that does not.
- Send each frame 3× back-to-back.
- `WIFI_PROTOCOL_LR` — Espressif's long-range PHY, ~7 dB more sensitivity than
  802.11b. Every node here is an ESP32, so there is no compatibility cost, and
  floor-to-floor through concrete is exactly the marginal link it is for.
- Channel 1, maximum TX power (84 quarter-dBm, quantised to 20 dBm).
- A frame failing magic, version, or CRC is dropped silently and counted.

---

## 5. The algorithm port

`src/floor_monitor.h` — board-agnostic, no `Arduino.h`, no allocation, so the
`native` environment compiles the exact code the ESP32 runs.

Four places a port silently diverges from the Python reference:

1. **`double`, not `float`.** `_trusted_rate()` computes
   `med²/(med² + (k·mad)²)` on numbers around 1e-4. float32 does not survive that.
2. **`np.std` is population std (ddof = 0).** The sample std is 12% larger over a
   5-window, which shifts the stillness threshold.
3. **`heights` / `stop_counts` dicts → fixed arrays.** `int16` floor index with
   origin +32 in a 64-entry table plus an occupied bitmap. Out-of-range indices
   clamp and raise a flag rather than growing.
4. **`estimate_pitch`'s sweep** (2.2 → 4.0 m, step 5e-4) runs once over 12 jumps:
   ~43k double operations, microseconds on this chip. Port it literally.

Every constant in ALGORITHM.md §7 is carried over unchanged. Structure mirrors
`floor_algorithm.py` function for function — `update`, `_close_dwell`, `_arrive`,
`_confirm`, `_revisit_rate`, `_trusted_rate`, `_replay`, `_learn`,
`_refine_pitch`, `estimate_pitch` — so the two can be diffed by eye.

### 5.1 Persistence

Pitch, the learned height ladder, stop counts, current floor index, `ref`,
odometer, trips, stops, and the 24 h buckets are written to NVS **every 5 minutes
when something has changed**. That is 288 writes/day. Saving on every confirmed
stop would be ~2000/day, which is a flash-endurance problem: the reference capture
has 256 confirmed stops in 3 h.

On boot the **building model** is restored - pitch, the height ladder, stop
counts, the odometer - so a reboot or battery swap does not restart the 5-minute
bootstrap. The car's **position is not restored**, and an earlier version of this
section got that wrong:

- The saved altitude reference is absolute, and weather moves it by metres over
  the hours a pack spends charging. It is re-taken from the first live sample.
- The saved floor is up to 5 minutes old even after a momentary blip, and
  arbitrarily stale if the car ran while the node was dark. The algorithm has no
  absolute anchor (ALGORITHM.md §8), so an index that starts a floor out would
  stay a floor out forever.

So after a restore the node **withholds the floor (screens show `--`) until the
car has been seen at both the lowest and the highest learned landing**. At that
point exactly one offset fits the trip history, and it is applied. After putting
the pack back, ride to floor 1 and floor 10, in either order. A span of visits
wider than the building means a rounding went wrong, and the search restarts
rather than locking in a bad offset. While unanchored, stops still count on the
odometer but teach nothing to the ladder, since their indices may be shifted.

A genuinely fresh unit still withholds output until the pitch is established,
per ALGORITHM.md §8.

A stored record carries a schema version and a CRC; a mismatch is discarded and
treated as a cold boot.

### 5.2 The 24-hour odometer

24 rolling one-hour buckets in RAM. They are written into the saved record but
deliberately never read back on restore: they are indexed by uptime and there is
no RTC, so a restored bucket cannot be placed on any timeline. There is no RTC — buckets are
indexed by `uptime / 3600 mod 24`, and advancing into a bucket clears it. "Last
24 h" therefore means "the last 24 hourly buckets", which is what the display
claims.

---

## 6. Displays

320×240 landscape.

```
┌────────────────────────────┬──────────────┐
│                            │      ▲       │   ▲/▼ only while moving
│      ██████     ██         │    UP        │
│      ██  ██     ██         │              │
│      ██  ██     ██         │  12.7 V      │   colour-coded bar
│      ██  ██     ██         │  ■■■■■□      │
│      ██████     ██         │              │
│                            │  2.1 mi      │   last 24 h
│                            │  today       │
└────────────────────────────┴──────────────┘
```

- **Big digits are drawn as vector 7-segment shapes**, not a bundled font. Any
  font large enough looks soft at ~180 px, and vectors cost nothing.
- While moving, the number tracks `posQ8` so it sweeps 3 → 4 → 5; on arrival it
  snaps to the confirmed `floor`.
- Redraws are region-limited via sprites, so the panel does not flicker.
- Floor labels come from a compile-time table, `-DFLOOR_LABELS="1,2,...,10"`.
  Simmons serves floors 1–10 with no basement, so index *n* maps to label *n*,
  but the table is where a basement or a skipped floor would be handled.
- **Staleness is measured against the STATS heartbeat, never against STATE.**
  STATE only flows while the car moves (§2.2), so silence on it is the normal
  parked condition — the floor shown is current, nothing is wrong. Timing the
  dim against STATE, as an earlier version of this section did at 10 s, leaves
  every screen dimmed through every idle period: most of a working day and all
  of a night. So: **no STATS for 150 s dims** the readout (two missed heartbeats
  plus margin — one miss must never dim it, since §9 says the mesh has no
  delivery guarantee and a threshold that flapped on a single loss would have
  ten screens blinking), and **no STATS for 180 s greys it out** and turns the
  RGB LED amber, so a dead link is visible from the corridor.
- **Battery warnings (§3.2):** CHARGE SOON replaces the battery bar with an
  amber badge; CHARGE BATTERY adds a steady full-width red banner along the
  bottom and turns the LED steady red, outranking amber. Steady, not flashing:
  these are public corridors and a red band is already unmissable. The number
  moved up 8 px to leave room for the banner rather than overlapping it.
- The LDR on GPIO34 drives backlight PWM on GPIO21 for night dimming.
- Distance is extrapolated locally between heartbeats from observed floor changes
  × the transmitted pitch, then corrected to the transmitter's figure on each
  STATS packet — so it ticks in real time but all ten screens agree every minute.

---

## 7. Verification

### 7.1 Host unit tests — `pio test -e native`

- `test/test_elev_packet/` — round-trip every field of both formats at limits and
  boundaries; truncated, wrong-tag and wrong-length inputs. No corrupt-CRC case:
  neither LoRa format carries an application CRC (§4.1), so there is nothing for
  a test to corrupt. That case lives in the mesh suite below.
- `test/test_mesh_packet/` — wrap/unwrap, hop decrement, CRC rejection, dedup ring
  behaviour including `origSeq` wraparound.
- `test/test_floor_monitor/` — synthetic lattice ascents/descents, door cycles
  below `MIN_JUMP_M`, off-lattice plateau rejection, bootstrap replay, and the
  shrinkage behaviour of `_trusted_rate()` under clustered vs scattered input.

### 7.2 Replay against the real capture

`sim/replay_main.cpp` builds in the `native` environment, streams
`elevatormons/data/baro-20260910-195011.csv` through the **actual C++
`FloorMonitor`**, and emits a CSV of broadcasts.
`sim/compare_to_python.py` diffs that against `floor_algorithm.py` sample by
sample.

The capture has **49 dropouts totalling 570 missing samples, worst case 41 s** —
radio loss, which the real node never sees because it holds the sensor. Gaps are
filled by linear interpolation of *pressure* onto an even 1 Hz grid, and filled
samples are marked in the output. The 41 s gap becomes an invented smooth ride;
that is documented, not hidden.

**The gate that matters** is the first row: the C++ floor sequence must be
identical to the Python reference's, sample for sample, on the same input. That is
what "the port is faithful" means. The absolute numbers below only bound how far
the gap-filled run may drift from the published measurement.

| quantity | required | ALGORITHM.md §5 (raw capture) |
|---|---|---|
| floor sequence vs Python | identical over all 10,950 samples | — |
| floors served | 10 | 10 |
| learned pitch | 2.871 m ± 1 mm | 2.871 m |
| distance travelled | 3409 m ± 0.1% | 3409 m |
| floor-to-floor moves | 357 ± 1 | 356 |
| confirmed stops | 255 ± 1 | 256 |

**Trips and stops differ from §5 by one in each direction, and that is correct.**
§5 measured the *raw* capture, which contains the 49 dropouts. This replay runs on
the gap-filled stream the node would actually have seen. Filling the worst hole —
41 s — invents one smooth ride across it, which is one extra floor-to-floor move
and one fewer dwell long enough to confirm. The **Python reference produces 357 /
255 on this input too**, so the two implementations still agree exactly; the
comparator checks both against the gates so a future divergence surfaces as C++
disagreeing with Python rather than as a moved goalpost.

---

## 8. Repository layout

```
platformio.ini        envs: elevator_tx · bridge_rx · floor_display · native
src/
  crc16.h  elev_packet.h  mesh_packet.h  floor_monitor.h     board-agnostic
  bmp390_sensor.{h,cpp}  lora_link.{h,cpp}                   adapted from elevatormons
  espnow_mesh.{h,cpp}  battery.{h,cpp}  nvs_model.{h,cpp}
  display_ui.{h,cpp}
  elevator_tx.cpp  bridge_rx.cpp  floor_display.cpp          the three mains
test/   test_elev_packet/  test_mesh_packet/  test_floor_monitor/
sim/    replay_main.cpp  compare_to_python.py
docs/   HARDWARE.md  FLASHING.md  PROTOCOL.md  ALGORITHM_PORT.md  MESH.md
```

Code from `elevatormons` is copied in and adapted, not referenced — that repo is
the bring-up bench and is not modified by this project.

---

## 9. Known limits carried forward

Everything in ALGORITHM.md §8 still applies: no absolute anchor, ~1.5–2×
turbulence headroom over a gusty evening, the uniform-pitch assumption in the
ladder clamp, and constants tuned to one building and one sensor. Persisting the
model to NVS removes the cold-boot window in practice but does not change any of
these.

New to this system:

- **A flood mesh has no delivery guarantee.** Three sends plus multiple paths make
  loss unlikely, not impossible. A display showing a stale floor is the expected
  failure mode, which is why staleness is displayed rather than hidden.
- **Battery voltage is ±2–3% before calibration**, roughly ±0.4 V at 12 V. Enough
  to answer "does this need charging?", not enough for a fuel gauge.
- **The 24 h window is uptime-relative**, not wall-clock. After a reboot it
  reports less than 24 h of history and does not pretend otherwise.

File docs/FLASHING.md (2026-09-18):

# Flashing

Thirty-eight boards, three firmwares, nine environments, one toolchain.
Everything here is run from the repository root, `simmevator/`, because
PlatformIO finds `platformio.ini` by walking up from the working directory.

Six of the thirty-eight are XIAO ESP32S3 modules with a Wio-SX1262 stacked on
top and distinctly odd USB behaviour - a car transmitter and a mid-shaft bridge
for each of the three shafts. The other thirty-two are ELEGOO CYD panels, and
they no longer all take the same binary: there is one display image per shaft,
and the three are indistinguishable on the bench. The thirty-two are the tedious
part, and there is a loop for it further down.

---

## 1. Getting PlatformIO

PlatformIO Core is a Python program. The installer drops it in a virtualenv
under `~/.platformio/penv/` and does **not** put it on `PATH`.

If you already have it:

```bash
~/.platformio/penv/bin/pio --version
```

If that prints a version, skip to the PATH note. If it does not:

```bash
python3 -c "$(curl -fsSL https://raw.githubusercontent.com/platformio/platformio-core-installer/master/get-platformio.py)"
```

Installing the VS Code PlatformIO IDE extension gets you the same `penv` - the
extension is a front end over exactly this core, so either route works and they
share one toolchain directory.

### Putting `pio` on PATH

For the current shell only:

```bash
export PATH="$HOME/.platformio/penv/bin:$PATH"
```

To make it permanent, on the zsh that macOS ships:

```bash
echo 'export PATH="$HOME/.platformio/penv/bin:$PATH"' >> ~/.zshrc
```

Open a new terminal afterwards, or `source ~/.zshrc`.

If you would rather not touch `PATH` at all, every command in this document
works with the full path substituted for `pio`:

```bash
~/.platformio/penv/bin/pio run -e bridge_rx_a -t upload
```

The rest of this document writes `pio`. Expand it in your head if you skipped
the PATH step.

### First build is slow

The first `pio run` for an ESP32 environment downloads the Espressif platform,
the Arduino framework and the xtensa/riscv toolchains - several hundred MB,
several minutes. Later builds are cached. The two host environments (`native`,
`sim`) need only a C++17 compiler and are fast from the start.

---

## 2. What goes on which board

Nine environments, three roles across three shafts. The sources are identical
for all three shafts; four build flags are the entire difference, which is
exactly what makes a mis-flashed board hard to see.

| Shaft | Board | Count | Environment | LoRa | Mesh ch | `ELEV_TX_ID` | Labels |
|---|---|---|---|---|---|---|---|
| A | Car transmitter - XIAO + Wio-SX1262 + BMP390 | 1 | `elevator_tx_a` | 913.0 MHz | - | `0x41` `'A'` | - |
| A | Mid-shaft bridge - XIAO + Wio-SX1262 | 1 | `bridge_rx_a` | 913.0 MHz | 6 | accepts `'A'` | - |
| A | Floor display - ELEGOO CYD 2.8" | 11 | `floor_display_a` | - | 6 | - | 11: `B,1..10` |
| B | Car transmitter | 1 | `elevator_tx_b` | 915.0 MHz | - | `0x42` `'B'` | - |
| B | Mid-shaft bridge | 1 | `bridge_rx_b` | 915.0 MHz | 1 | accepts `'B'` | - |
| B | Floor display | 10 | `floor_display_b` | - | 1 | - | 10: `1..10` |
| C | Car transmitter | 1 | `elevator_tx_c` | 917.0 MHz | - | `0x43` `'C'` | - |
| C | Mid-shaft bridge | 1 | `bridge_rx_c` | 917.0 MHz | 11 | accepts `'C'` | - |
| C | Floor display | 11 | `floor_display_c` | - | 11 | - | 11: `B,1..10` |

Elevator B's four values are the single-elevator system's values, unchanged. The
two XIAO roles are ESP32-S3 with native USB-Serial-JTAG (section 7); the CYD is
an ESP32-WROOM-32 behind a CH340 (section 8). Upload with
`pio run -e <env> -t upload`, and add `-t monitor` to open the serial console
straight after:

```bash
pio run -e elevator_tx_a -t upload -t monitor
```

All nine run the console at 115200 baud (`monitor_speed` in `[base]`).

There are now two independent ways to flash the wrong image, and they fail very
differently.

**Wrong role, and it is loud.** `elevator_tx_*` builds the BMP390 driver, the
battery sense and NVS persistence; `bridge_rx_*` builds the ESP-NOW mesh instead
and never touches a sensor. Flashing the bridge firmware onto a car node gives
you a board that is deaf to its own barometer and happily floods nothing. The
console says so on the first boot.

**Wrong shaft, and it is quiet.** Put shaft C's transmitter image on shaft A's
car and bridge A hears nothing at all - it is listening on 913.0 MHz while that
car talks on 917.0 - which reads exactly like a dead SX1262. Worse, bridge C
*will* hear it, accept it, and publish it, because the packet carries `txId`
`'C'` and is a genuine C packet as far as any receiver can tell. Shaft C's
eleven screens would then show shaft A's car. The bridge's `txId` filter
catches a packet from a foreign shaft; it cannot catch an identity you flashed
into the transmitter. That is what section 2.1 is for.

`pio run` with no `-e` builds all nine firmware environments (that is what
`default_envs` in `[platformio]` is for) but uploads nothing, so it is a useful
"does this still compile" check - and see section 10 for why compiling cleanly
is not, on its own, evidence that the nine images differ.

### 2.1 Label every board before it leaves the bench

Write the shaft letter on the board before you unplug the USB cable, in the
same motion as the upload. Not later, not at the end of the batch. A role and a
letter is the whole label: `A-TX` and `A-BR` on the two XIAOs, a bare `A` on
each of the eleven displays, in ink or tape on the back of the case next to the
USB connector where it is readable after installation. Displays need nothing
more than the letter, because within a shaft they are genuinely interchangeable
(section 6). Keep three piles, one per shaft, and a board joins a pile only
after it is labelled.

The failure this prevents is specifically an A-versus-C failure. Both shafts
have eleven landings and therefore the identical label table, `B,1..10`, and
`FLOOR_LABEL_COUNT` 11. A panel running `floor_display_a` and a panel running
`floor_display_c` boot to the same layout, the same glyphs and the same startup
screen. They differ in one number that never appears on the panel: the mesh
channel, 6 versus 11. Channels 1, 6 and 11 are the non-overlapping set, so a
panel on the wrong one of them does not hear its landing's bridge weakly - it
does not hear it at all. `heard` stays at 0, nothing is ever handed to
`displayUpdate()` (`floor_display.cpp` draws only `if (gSeenAnyFrame)`), and the
panel sits on the boot splash - "Simmevator" over "waiting for the mesh" -
indefinitely. That is the same symptom as a dead bridge, a flat car pack, or a
panel simply out of mesh range. The one board that is actually wrong is the one
board that looks blameless.

Note what a mis-flashed panel does **not** do. It does not show a wrong floor,
because it decodes nothing. It does not show `--`, because `--` is a fully drawn
screen with no confirmed floor, and a drawn screen means frames are arriving
(section 12.2). And it does not show CHECK SHAFT, because that verdict is
derived from a STATS field it never receives.

**CHECK SHAFT (section 12) cannot catch this case**, and not only for the reason
above: the check compares the transmitter's floor count against
`FLOOR_LABEL_COUNT`, and A and C both say 11. B is the easy one in both
directions - its ten-entry table disagrees with the other two, so a label table
crossed in `platformio.ini` surfaces immediately - but two images that differ
only in a channel number have no software backstop at all. Ink is the backstop.

The second witness is the firmware itself: every one of the nine builds names
its shaft in the first few lines it prints (section 9 - on a car node that is
the `[tx] txId=` line rather than the radio banner). So the ink is checkable.
Open the console, read the letter, compare. If they disagree, believe the
firmware and reflash - the firmware is what the board will actually do. For a
car node that means USB, which means the pack comes off first; see section 3.

---

## 3. Unplug the battery before flashing the transmitter

**Do this before the USB cable goes in. Every time.**

Each of the three car nodes is powered by feeding the MP1584EN buck's 5 V
output into the XIAO's **5V pad**, which is the board's supply input. That pad
and the USB connector's VBUS are the same node, so plugging in USB while the
pack is connected ties the buck's output straight to the host's 5 V rail - two
supplies across each other, with the buck also back-feeding whatever you are
flashing from. Nothing in that arrangement is current limited by design.

So: pull the spade terminals, then plug in USB. That is what the spade
terminals are for - they exist so the pack can come off for charging, and
flashing is the same disconnect.

The three bridges and the thirty-two displays have no battery and no second
supply. Plug them in and go.

This rule is also the reason section 12 exists. `HARDWARE.md` §3.5
forbids USB while the buck feeds the 5V pad, and a commissioning run is by
definition a car running on its pack - so during the one procedure that most
needs a console, the car node is the one board that may not have one.

While the terminals are off, it is also worth metering the buck's output before
reconnecting - see `docs/HARDWARE.md`. It should read 5 V, and if your module
has a trim pot rather than a fixed output, that is a screw a jostled enclosure
can move.

---
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

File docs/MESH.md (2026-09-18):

# The ESP-NOW flood

Eleven ESP32s in elevator B - the bridge on floor 5 and one display on each of
floors 1 through 10 - share one broadcast address and one rule: *if you have
not seen this `origSeq` before, wait a random moment and send it on once*.
There is no routing table, no pairing, no per-floor configuration and no MAC
address written down anywhere. A display is interchangeable with a spare
straight out of the box.

Elevators A and C run that same mesh with twelve nodes, the extra one being the
basement display. The three shafts are three separate floods on three separate
channels, and no node ever hears another shaft's traffic - that is the central
decision of the three-elevator deployment and it has its own section, §13.
Everything between here and there describes one shaft, and says so wherever the
node count is part of the arithmetic.

This file covers why it is built that way, which numbers are safe to turn, and
how to work out what is wrong while standing in the stairwell with a laptop.
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

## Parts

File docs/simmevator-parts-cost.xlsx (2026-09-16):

Simmevator Parts List
# | Item | Link | Units per Pack | Transmitter | Bridge | Displays | Units Needed | Packs | Price per Pack | Total
1 | Seeed Studio XIAO ESP32S3 & Wio-SX1262 LoRa Kit | https://www.amazon.com/dp/B0F8TSW1WZ | 1 | 1 | 1 | 0 |  |  | $18.99
2 | CJMCU-390 BMP390 Barometric Pressure Sensor | https://www.amazon.com/dp/B0C6CKWXYR | 1 | 1 | 0 | 0 |  |  | $14.99
3 | 12V 10Ah LiFePO4 Battery | https://www.amazon.com/dp/B0F9W5CTYT | 1 | 1 | 0 | 0 |  |  | $34.99
4 | PZ.P 15A 12V/24V Smart Battery Charger (LiFePO4) | https://www.amazon.com/dp/B0DYNN76TH | 1 | 1 | 0 | 0 |  |  | $29.99
5 | MP1584EN 5V Buck Converter (5 pcs) | https://www.amazon.com/dp/B0B779ZYN1 | 5 | 1 | 0 | 0 |  |  | $8.99
6 | Female Spade Battery Terminal Leads (6 pcs) | https://www.amazon.com/dp/B0B8GNKV2C | 6 | 2 | 0 | 0 |  |  | $11.99
7 | USB-C 20W Wall Charger (4 pack) | https://www.amazon.com/dp/B0D411N89G | 4 | 0 | 1 | 10 |  |  | $12.99
8 | USB-C to USB-C Cable (5 pack) | https://www.amazon.com/dp/B0FWKMJX4K | 5 | 1 | 1 | 10 |  |  | $7.99
9 | ELEGOO ESP32 2.8" Touch Display (2 pack) | https://www.amazon.com/dp/B0FJQ6RK39 | 2 | 0 | 0 | 10 |  |  | $26.99
10 | Command Poster Strips (64 strips) | https://www.amazon.com/dp/B0751VFF2X | 64 | 0 | 0 | 40 |  |  | $10.99
 |  |  |  |  |  |  |  | Subtotal
 |  |  |  |  |  |  |  | Sales Tax Rate (Boston, MA) |  | 6.25%
 |  |  |  |  |  |  |  | Sales Tax
 |  |  |  |  |  |  |  | Total

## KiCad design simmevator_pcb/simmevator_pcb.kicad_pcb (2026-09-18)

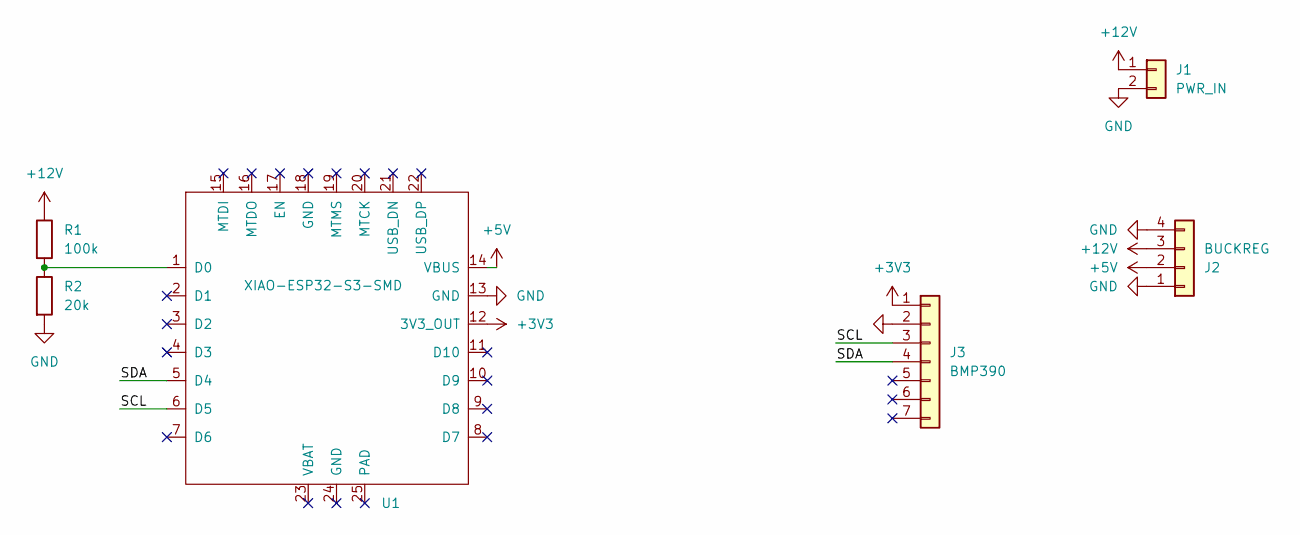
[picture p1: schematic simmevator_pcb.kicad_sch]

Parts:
J1: PWR_IN; SolderWire-1.5sqmm_1x02_P6mm_D1.7mm_OD3mm_Relief
J2: BUCKREG
J3: BMP390; PinHeader_1x07_P2.54mm_Vertical
R1: 100k; R_Axial_DIN0207_L6.3mm_D2.5mm_P10.16mm_Horizontal
R2: 20k; R_Axial_DIN0207_L6.3mm_D2.5mm_P10.16mm_Horizontal
U1: XIAO-ESP32-S3-SMD; XIAO-ESP32-S3-DIP

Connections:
+3V3: J3.1, U1.12 (3V3_OUT)
+5V: J2.2, U1.14 (VBUS)
+12V: J1.1, J2.3, R1.1
/SCL: J3.3, U1.6 (D5)
/SDA: J3.4, U1.5 (D4)
GND: J1.2, J2.1, J2.4, J3.2, R2.2, U1.13 (GND)
unnamed: R1.2, R2.1, U1.1 (D0)

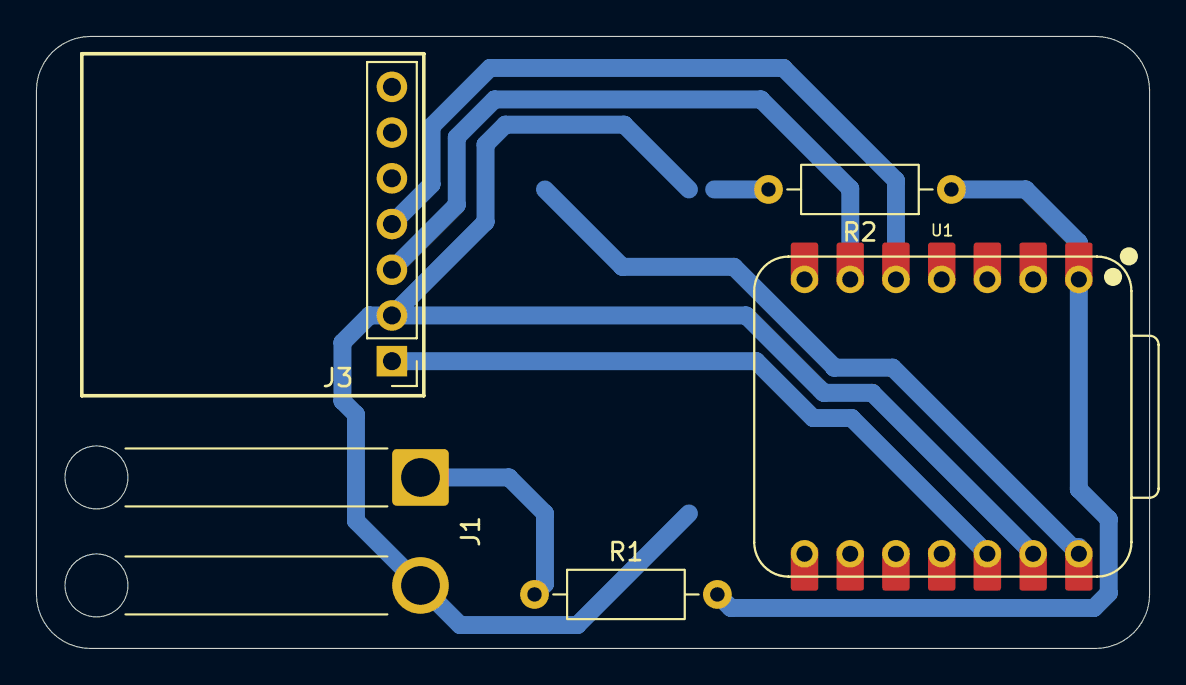
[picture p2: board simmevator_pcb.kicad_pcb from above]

Board: 2 copper layers, 61.8 x 34.0 mm, 6 parts (1 on the bottom side), 7 nets.

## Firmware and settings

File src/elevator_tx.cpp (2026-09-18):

//
// The car node: barometer in, floor out, LoRa on a battery.
//
// Everything the system knows about where the elevator is is decided here, on
// the one board that holds the sensor and therefore sees an unbroken sample
// stream (spec 1). The radio only carries the answer; losing a packet ages a
// display, it cannot corrupt a floor.
//
// ---------------------------------------------------------------------------
// Three clocks, and why they are not one
// ---------------------------------------------------------------------------
// 4 Hz  the barometer is read, and the reading is tested for stillness. This
//       clock exists only to notice that the car has started moving, so the
//       first STATE packet goes out about half a second after departure
//       instead of up to two seconds after it.
// 1 Hz  one of those readings - the freshest - is handed to FloorMonitor.
//       Every window length and rate threshold in ALGORITHM.md section 7 is
//       expressed in samples per second and was measured at 1 Hz, so feeding
//       the monitor at 4 Hz would quietly re-tune the whole algorithm. The
//       BMP390 free-runs at 25 Hz internally, so reading it four times a
//       second does not change what the once-a-second read returns.
// event STATE goes out while the car moves and for STATE_HOLD_AFTER_STOP_MS
//       after; STATS goes out on its own 60 s heartbeat regardless.
//
// ---------------------------------------------------------------------------
// Why the loop sleeps
// ---------------------------------------------------------------------------
// Spec 2.2 budgets ~3 mA light-sleeping against ~25 mA awake, and the whole
// 30-day figure rests on the node being asleep for almost all of every second.
// Deep sleep is not available: the algorithm needs the stream unbroken, and a
// deep-sleep wake is a reboot. So the loop does its due work and then sleeps
// to the next deadline with the SX1262 sleeping too - the radio idles at
// several mA in standby, which alone would be a third of the budget.
//
// The sleep is measured rather than assumed. esp_light_sleep_start() returns
// near the requested time, not at it, and the difference is the difference
// between the budget above and a battery that lasts three weeks - so the
// STATS line reports what was asked for and what was actually spent.
//
// ---------------------------------------------------------------------------
// Clocks and wrapping
// ---------------------------------------------------------------------------
// millis() wraps every 49.7 days and this node is meant to run for months, so
// the schedule runs on esp_timer_get_time(): 64-bit microseconds, monotonic
// across light sleep, and 584,000 years from wrapping. Every deadline is still
// compared as an unsigned difference, which is the form that survives a wrap
// wherever one can happen - nvsModelMaybeSave() still takes millis() and
// handles its own.
//

#include <Arduino.h>
#include <esp_sleep.h>
#include <esp_timer.h>
#include <math.h>

#include "battery.h"
#include "bmp390_sensor.h"
#include "elev_packet.h"
#include "floor_monitor.h"
#include "lora_link.h"
#include "nvs_model.h"

// ---------------------------------------------------------------------------
// Schedule - the real values come from [env:elevator_tx] in platformio.ini,
// where the power-budget arithmetic behind each one is written down. These
// fallbacks only keep the file compilable on its own.
// ---------------------------------------------------------------------------
#ifndef FLOOR_SAMPLE_INTERVAL_MS
#define FLOOR_SAMPLE_INTERVAL_MS 1000
#endif
#ifndef STILLNESS_PROBE_INTERVAL_MS
#define STILLNESS_PROBE_INTERVAL_MS 250
#endif
#ifndef STATE_INTERVAL_MS
#define STATE_INTERVAL_MS 2000
#endif
#ifndef STATE_HOLD_AFTER_STOP_MS
#define STATE_HOLD_AFTER_STOP_MS 10000
#endif
#ifndef STATS_INTERVAL_MS
#define STATS_INTERVAL_MS 60000
#endif

// Which shaft this transmitter belongs to: ASCII 'A', 'B' or 'C', so a hex
// dump of a capture reads E0 42 and names the car without a lookup table
// (spec 3). There is deliberately no default. Three cars sharing one id would
// let each bridge's txId filter (spec 5.2) accept every shaft's packets, and
// the symptom would be a display showing another shaft's floor - plausible,
// silent, and indistinguishable from a bad model. A build error here costs a
// minute; that failure costs a commissioning trip.
#ifndef ELEV_TX_ID
#error "ELEV_TX_ID is not set - build one of elevator_tx_a/_b/_c, which pull it from [elev_a]/[elev_b]/[elev_c] in platformio.ini (spec 5.1)"
#endif

// Re-attempt sensor bring-up this often while it is missing, matching
// elevatormons' baro_tx. A node whose BMP390 comes up late still works.
#ifndef SENSOR_RETRY_INTERVAL_MS
#define SENSOR_RETRY_INTERVAL_MS 5000
#endif

// Core clock. The spec 2.2 transmit figure of 140 mA is the SX1262 at +22 dBm
// plus an ~22 mA core, which is 80 MHz - not the 240 MHz the board default
// leaves it at. RadioLib busy-polls DIO1 for the whole 297 ms of every packet,
// so the clock the core happens to be at is spent for the entire airtime. 80 is
// the floor: the USB-Serial-JTAG PHY stops working below it.
#ifndef TX_CPU_MHZ
#define TX_CPU_MHZ 80
#endif

// Backoff for an NVS that is failing every write. The first retry waits a
// second, then it doubles to a minute - long enough that a dead partition costs
// nothing, short enough that a transient recovers on its own.
#ifndef NVS_FAIL_BACKOFF_MIN_MS
#define NVS_FAIL_BACKOFF_MIN_MS 1000
#endif
#ifndef NVS_FAIL_BACKOFF_MAX_MS
#define NVS_FAIL_BACKOFF_MAX_MS 60000
#endif
#ifndef NVS_FAIL_PRINT_LIMIT
#define NVS_FAIL_PRINT_LIMIT 3
#endif

// Below this the entry and exit cost more than the sleep saves, so the loop
// just falls through and arrives at the deadline a moment early.
#define LIGHT_SLEEP_MIN_US 3000

#define US_PER_MS 1000ULL
#define US_PER_S  1000000ULL

// ---------------------------------------------------------------------------
// State
// ---------------------------------------------------------------------------
static FloorMonitor   monitor;
static FloorBroadcast bc;            // last broadcast, held across a dropped sample

static bool           sensorUp     = false;
static Bmp390Reading  probeSample;  // freshest 4 Hz reading
static bool           sampleFresh  = false;   // cleared by the 1 Hz step, so a
                                              // stale reading is never re-fed
static bool           sensorErr    = false;   // STATE bit 4 / STATS bit 0
static uint32_t       sensorSkips  = 0;

// Trailing window for the motion-onset probe. Same threshold and depth as the
// algorithm's own stillness test, but running at 4 Hz it spans 1.25 s rather
// than 5 s. It is not a second opinion on where the car is - FloorMonitor's
// `moving` stays authoritative - it only decides when to start transmitting.
static double   stillRing[FLOOR_STILL_WIN];
static uint8_t  stillCount = 0;

// The STATE stream runs until this deadline, which every sign of motion pushes
// out. holdActive distinguishes "the hold has expired" from "the node has only
// just booted", which an all-zero deadline cannot.
static uint64_t holdUntilUs = 0;
static bool     holdActive  = false;

static uint64_t lastProbeUs = 0;
static uint64_t lastFloorUs = 0;
static uint64_t lastStateUs = 0;
static uint64_t lastStatsUs = 0;
static uint32_t lastRetryMs = 0;
static uint32_t nvsFailBackoffMs = 0;   // 0 = healthy, no backoff in effect
static uint32_t nvsLastFailMs    = 0;
static uint32_t nvsFailCount     = 0;

static uint8_t  stateSeq = 0;   // one counter per format: the two streams run at
static uint8_t  statsSeq = 0;   // different cadences, so a shared seq would make
                                // per-stream loss impossible to measure
static uint32_t stateSent = 0;
static uint32_t statsSent = 0;
static uint32_t txFails   = 0;

// Sleep accounting for the window since the last STATS line.
static uint64_t winSleptUs = 0;
static uint64_t winReqUs   = 0;
static uint32_t winNaps    = 0;
static uint32_t sleepRejects = 0;
static uint64_t winStartUs = 0;

// Changes worth persisting, watched rather than hooked: FloorMonitor has no
// callback, and a confirmed stop is exactly when these move.
static uint32_t seenTrips  = 0;
static uint32_t seenStops  = 0;
static bool     seenReady  = false;

static uint8_t packetBuf[ELEV_MAX_PACKET_BYTES];

// ---------------------------------------------------------------------------
// Helpers
// ---------------------------------------------------------------------------
static inline uint64_t nowUs() {
  return (uint64_t)esp_timer_get_time();
}

// Advances the deadline rather than restarting it from now, so a cadence does
// not drift by however long the rest of the loop took. If something held the
// loop up for more than a whole interval - a 494 ms STATS transmit against the
// 250 ms probe - the schedule skips ahead instead of firing a burst of
// catch-up work with bunched timestamps.
static bool due(uint64_t now, uint64_t *last, uint64_t interval) {
  if (now - *last < interval) return false;
  *last += interval;
  if (now - *last >= interval) *last = now;
  return true;
}

static uint8_t clampU8(long v) {
  if (v < 0) return 0;
  if (v > 255) return 255;
  return (uint8_t)v;
}

static uint16_t clampU16(double v) {
  if (!(v > 0.0)) return 0;
  if (v > 65535.0) return 65535;
  return (uint16_t)lround(v);
}

static uint32_t clampU32(double v) {
  if (!(v > 0.0)) return 0;
  if (v > 4294967295.0) return 4294967295u;
  return (uint32_t)v;
}

static int16_t clampI16(double v) {
  if (!isfinite(v)) return 0;
  if (v < -32768.0) return -32768;
  if (v > 32767.0) return 32767;
  return (int16_t)lround(v);
}

// FloorDirection and ElevDirection happen to share their numbering. Mapped
// rather than cast so that the wire format and the algorithm stay free to
// diverge without a silent off-by-one between them.
static ElevDirection wireDirection(FloorDirection d) {
  switch (d) {
    case FLOOR_DIR_UP:   return ELEV_DIR_UP;
    case FLOOR_DIR_DOWN: return ELEV_DIR_DOWN;
    case FLOOR_DIR_IDLE: break;
  }
  return ELEV_DIR_IDLE;
}

static const char *directionName(FloorDirection d) {
  switch (d) {
    case FLOOR_DIR_UP:   return "up";
    case FLOOR_DIR_DOWN: return "down";
    case FLOOR_DIR_IDLE: break;
  }
  return "idle";
}

// ---------------------------------------------------------------------------
// Transmit
// ---------------------------------------------------------------------------
static bool transmit(size_t len, const char *what) {
  uint64_t start = nowUs();
  int16_t state = loraTransmit(packetBuf, len);
  uint32_t airMs = (uint32_t)((nowUs() - start) / US_PER_MS);

  // Back to sleep immediately: standby is several mA and the next packet is at
  // least two seconds away. loraTransmit() wakes the radio itself.
  loraSleep();

  if (state != RADIOLIB_ERR_NONE) {
    txFails++;
    Serial.printf("[tx] %s FAILED %d (%s) after %lu ms\n", what, state,
                  loraStatusName(state), (unsigned long)airMs);
    return false;
  }
  return true;
}

static void sendState(uint64_t now, const char *why) {
  ElevState s;
  s.txId  = ELEV_TX_ID;
  s.seq   = stateSeq++;
  // 0 is the wire's "model not ready". A fresh node withholds the floor rather
  // than broadcasting one it has not earned - ALGORITHM.md section 8.
  s.floor = bc.modelReady ? clampU8(bc.floor) : 0;
  s.posQ8 = bc.modelReady
                ? clampI16(bc.posFloors * (double)ELEV_POS_UNITS_PER_FLOOR)
                : 0;
  s.state = elevStateByte(bc.moving, wireDirection(bc.direction), bc.modelReady,
                          sensorErr);
  s.confidence = clampU8(lround(bc.confidence * 255.0));

  size_t len = elevStatePack(packetBuf, sizeof(packetBuf), &s);
  if (len == 0) return;   // only reachable through a programming error

  lastStateUs = now;
  if (!transmit(len, "STATE")) return;
  stateSent++;

  Serial.printf("[tx] STATE seq=%u floor=%u pos=%+.2f %s%s conf=%u (%s)\n",
                s.seq, s.floor, (double)s.posQ8 / ELEV_POS_UNITS_PER_FLOOR,
                bc.moving ? "moving " : "stopped ", directionName(bc.direction),
                s.confidence, why);
}

static void sendStats(uint64_t now) {
  // Once per STATS packet, not per loop: the divider is always connected and
  // the pack moves on a timescale of hours, so a minute-old reading is as good
  // as a fresh one and costs nothing.
  uint16_t mv = batteryReadMv();
  const BatteryLevel level = batteryLevelUpdate(mv);

  ElevStats s;
  s.txId       = ELEV_TX_ID;
  s.seq        = statsSeq++;
  s.batteryMv  = mv;
  s.dist24hM   = clampU16(bc.dist24hM);
  s.distTotalM = clampU32(bc.distanceM);
  s.pitchMm    = clampU16(bc.pitch * (double)ELEV_MM_PER_M);
  s.nFloors    = clampU8(bc.nFloors);
  s.trips      = clampU16((double)bc.trips);
  s.stops      = clampU16((double)bc.stops);
  s.uptimeS    = (uint32_t)(now / US_PER_S);
  s.flags      = elevStatsFlagsByte(sensorErr, bc.modelReady, nvsModelRestored(),
                                    level >= BATTERY_LOW,
                                    level == BATTERY_CRITICAL);
  s.tempC      = (int8_t)constrain(lround(probeSample.temperatureC), -128L, 127L);

  size_t len = elevStatsPack(packetBuf, sizeof(packetBuf), &s);
  if (len == 0) return;

  lastStatsUs = now;
  if (transmit(len, "STATS")) {
    statsSent++;
    Serial.printf("[tx] STATS seq=%u %u mV%s %.1f C | pitch=%u mm floors=%u "
                  "trips=%u stops=%u | %lu m total, %u m/24h | up %lu s "
                  "flags=0x%02X\n",
                  s.seq, s.batteryMv, level != BATTERY_OK ? " LOW" : "",
                  probeSample.temperatureC, s.pitchMm, s.nFloors, s.trips,
                  s.stops, (unsigned long)s.distTotalM, s.dist24hM,
                  (unsigned long)s.uptimeS, s.flags);
  }

  // The number the 30-day figure rests on. Requested against measured is the
  // part that cannot be assumed: the wake path costs what it costs.
  uint64_t windowUs = now - winStartUs;
  double pct = windowUs ? (100.0 * (double)winSleptUs / (double)windowUs) : 0.0;
  Serial.printf("[tx] sleep %.2f/%.2f s of %.2f s (%.1f%%) in %lu naps, "
                "%+.0f ms vs request%s | tx ok=%lu/%lu fail=%lu skips=%lu\n",
                winSleptUs / 1e6, winReqUs / 1e6, windowUs / 1e6, pct,
                (unsigned long)winNaps,
                ((double)winSleptUs - (double)winReqUs) / 1000.0,
                sleepRejects ? " (rejects seen)" : "",
                (unsigned long)stateSent, (unsigned long)statsSent,
                (unsigned long)txFails, (unsigned long)sensorSkips);

  winSleptUs = 0;
  winReqUs   = 0;
  winNaps    = 0;
  winStartUs = now;
}

// ---------------------------------------------------------------------------
// The 4 Hz probe
// ---------------------------------------------------------------------------
// How often the barometer is read. 4 Hz exists solely to catch motion ONSET;
// once the STATE stream is already running that job is done, and three of every
// four wakeups would do nothing but read a sample the 1 Hz step never looks at.
// At evening-peak traffic the hold is active ~90% of the time, so this is most
// of the probe's wakeups. It returns to 4 Hz the moment the hold expires, which
// is what keeps the next onset fast.
static uint64_t probeIntervalUs() {
  return (uint64_t)(holdActive ? FLOOR_SAMPLE_INTERVAL_MS
                               : STILLNESS_PROBE_INTERVAL_MS) * US_PER_MS;
}

static void pushStill(double alt) {
  // bmp390Read() calls a reading valid once the conversion returns, but the
  // altitude on top of it is a powf over the pressure ratio and comes back
  // non-finite if that ratio ever goes bad. One of those in the ring makes
  // stdPopulation() non-finite for the next 1.25 s, which fails the stillness
  // comparison and fires an onset packet for a car that never moved.
  if (!isfinite(alt)) return;
  if (stillCount < FLOOR_STILL_WIN) {
    stillRing[stillCount++] = alt;
    return;
  }
  for (uint8_t i = 1; i < FLOOR_STILL_WIN; i++) stillRing[i - 1] = stillRing[i];
  stillRing[FLOOR_STILL_WIN - 1] = alt;
}

static void noteMotion(uint64_t now) {
  holdUntilUs = now + (uint64_t)STATE_HOLD_AFTER_STOP_MS * US_PER_MS;
  holdActive  = true;
}

static void probe(uint64_t now) {
  Bmp390Reading r = bmp390Read();
  if (!r.valid) {
    // Not stored and not pushed into the ring. A failed conversion has no
    // altitude in it, and feeding the last good one forward would read as the
    // car holding perfectly still - which is exactly the wrong conclusion
    // while the sensor is out.
    return;
  }
  probeSample = r;
  sampleFresh = true;
  pushStill(r.altitudeM);

  if (holdActive) return;   // already transmitting; the 1 Hz monitor has it now
  if (stillCount < FLOOR_STILL_WIN) return;

  if (floor_detail::stdPopulation(stillRing, FLOOR_STILL_WIN) <= FLOOR_STILL_STD_M) {
    return;
  }

  // The whole reason this clock exists. Deferring this packet to the next 2 s
  // slot boundary would throw away the latency the 4 Hz probe was added to buy.
  noteMotion(now);
  Serial.printf("[tx] motion onset at %.2f s\n", now / 1e6);
  sendState(now, "onset");
}
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
void loop() {
  uint64_t now = nowUs();

  if (!sensorUp) {
    // Nothing probes while the sensor is down, but the probe deadline still
    // has to move: nextDeadline() takes the earliest of them, and one stuck in
    // the past makes it return `now` every pass. sleepUntil() then declines
    // every nap and the node spins at full current between bring-up retries -
    // the one state where it can least afford to.
    (void)due(now, &lastProbeUs, probeIntervalUs());
    uint32_t nowMs = millis();
    if (nowMs - lastRetryMs >= SENSOR_RETRY_INTERVAL_MS) {
      lastRetryMs = nowMs;
      sensorUp = bmp390BringUp("ELEVATOR TX SENSOR RETRY");
    }
  } else if (due(now, &lastProbeUs, probeIntervalUs())) {
    probe(now);
  }

  if (due(now, &lastFloorUs, (uint64_t)FLOOR_SAMPLE_INTERVAL_MS * US_PER_MS)) {
    stepAlgorithm(now);
  }

  if (holdActive) {
    if (now >= holdUntilUs) {
      holdActive = false;
      Serial.printf("[tx] STATE stream off at %.2f s\n", now / 1e6);
    } else if (now - lastStateUs >= (uint64_t)STATE_INTERVAL_MS * US_PER_MS) {
      sendState(now, "cadence");
    }
  }

  if (now - lastStatsUs >= (uint64_t)STATS_INTERVAL_MS * US_PER_MS) {
    sendStats(now);
  }

  sleepUntil(nextDeadline(nowUs()));
}

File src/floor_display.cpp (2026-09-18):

//
// The per-floor screen. One identical unit on every landing of one shaft -
// ten in elevator B, eleven each in A and C, which also serve a basement.
//
// This node is a renderer and a relay, and deliberately nothing else. It never
// runs the floor algorithm and it never infers a floor from anything but a
// received packet. Spec section 1: the decision belongs in the car, where the
// sensor is, so radio loss can only age what a screen shows - it can never
// corrupt it, and one received packet resyncs everything. A display that
// second-guessed the packet would turn every dropout into a correctness
// problem instead of a latency one.
//
// ---------------------------------------------------------------------------
// Why the relay is never made to wait for a repaint
// ---------------------------------------------------------------------------
// meshService() is where a frame whose jitter has expired actually goes back on
// the air. A TFT repaint is tens of milliseconds; the top floor is five hops
// from the bridge, so a display that redrew before servicing the mesh would add
// that delay once per hop, and a floor number arriving a fifth of a second late
// is visible to somebody standing in front of it.
//
// So the frame handler does packet arithmetic and nothing else - it records
// what arrived and sets a flag - and every pixel is written from loop(), after
// meshService() has returned. The dedup, the hop decrement and the rebroadcast
// decision all live in espnow_mesh.cpp and have already happened by the time
// the handler is called; what this file owes the mesh is simply to get out of
// its way quickly.
//
// ---------------------------------------------------------------------------
// What this node has to decide for itself
// ---------------------------------------------------------------------------
// Two things, both of which are about time rather than about the elevator:
// how stale the link is, and what the odometer reads between heartbeats.
// Everything else on the screen is a field out of a packet.
//
#include "display_ui.h"
#include "elev_packet.h"
#include "espnow_mesh.h"

// ---------------------------------------------------------------------------
// Cadences
// ---------------------------------------------------------------------------

// How often the screen is rebuilt when no packet has arrived. Nothing in the
// UI state moves on its own except the two staleness flags, and a quarter
// second of lag on a flag that has already waited ten seconds is not something
// anyone can see. A packet sets gDirty and repaints immediately, so this is not
// what governs how fast the floor number responds.
#ifndef UI_REFRESH_MS
#define UI_REFRESH_MS 250
#endif

// Dedup is reported as a delta rather than per frame. With the ten or eleven
// displays of one shaft each sending MESH_REPEATS copies, one STATE can produce
// twenty-odd duplicates at a well-connected node, and a line each would bury the
// frames that matter. The three shafts are on separate channels, so this count
// is always one shaft's own traffic.
#ifndef DEDUP_REPORT_MIN_MS
#define DEDUP_REPORT_MIN_MS 1000
#endif

// The periodic "what does this node think is going on" summary.
#ifndef SUMMARY_INTERVAL_MS
#define SUMMARY_INTERVAL_MS 30000
#endif

// Statute miles. The corridor reads miles; everything on the wire is metres,
// and this is the only place the two meet.
#define METRES_PER_MILE 1609.344f

// ---------------------------------------------------------------------------
// What the last packets said
//
// Touched only from meshService()'s frame handler and from loop(), both of
// which run on the Arduino task - nothing here is reachable from the WiFi
// callback, so none of it needs to be volatile or guarded.
// ---------------------------------------------------------------------------
static bool     gSeenAnyFrame = false;
static uint32_t gFirstFrameMs = 0;
static uint8_t  gBatteryLevel = DISPLAY_BATTERY_OK;  // latched on the car, per STATS

static bool     gHaveState   = false;
static uint32_t gLastStateMs = 0;
static bool     gHaveStats   = false;
static uint32_t gLastStatsMs = 0;

static uint8_t  gFloor      = 0;  // confirmed 1-based index, 0 = model not ready
static float    gPosition   = 0.0f;
static bool     gModelReady = false;
static bool     gMoving     = false;
static uint8_t  gDirection  = ELEV_DIR_IDLE;

static float    gBatteryVolts = 0.0f;
static float    gPitchM       = 0.0f;

// The three STATS fields the commissioning readout is built from (spec 4.3).
// All three were unpacked and thrown away before this change. gModelFloorsValid
// is what keeps the readout quiet for the first minute after boot, when there
// has been no heartbeat to compare FLOOR_LABEL_COUNT against.
//
// All three come from STATS, and they have to. The obvious alternative for
// model-ready is gModelReady, which STATE carries - but STATE only runs while
// the car moves and for STATE_HOLD_AFTER_STOP_MS after it stops, so on a
// display that booted into a parked shaft it is simply false, meaning "no STATE
// has arrived here yet" rather than anything about the car's model. Feeding
// that into the truth table alongside an nFloors that DID arrive reads as
// "the model is not ready but the span is right" - which is ANCHORING, so a
// healthy parked shaft would tell every screen to ride to both ends after any
// display reset. Taking all three from one packet keeps them one coherent
// snapshot of what the car said, instead of a mix of what it said and what
// this node happens to have heard.
static uint8_t  gModelFloors      = 0;
static bool     gModelFloorsValid = false;
static bool     gNvsRestored      = false;
static bool     gStatsModelReady  = false;

// The odometer, as a fixed baseline from the last heartbeat plus whatever this
// node has watched happen since. See accrueDistance().
static float    gDist24hBaseM     = 0.0f;
static uint32_t gFloorsSinceStats = 0;
static uint8_t  gLastFloorSeen    = 0;

static bool     gDirty         = false;
static uint32_t gLastDrawMs    = 0;
static uint32_t gDedupReported = 0;
static uint32_t gDedupReportMs = 0;
static uint32_t gSummaryMs     = 0;
static uint32_t gBadFrames     = 0;  // right envelope, unusable contents

// ===========================================================================
// Packet handling
// ===========================================================================
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

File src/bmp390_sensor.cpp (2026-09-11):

//
// BMP390 bring-up and reads over Wire1. See bmp390_sensor.h for the wiring and
// the reasoning behind the oversampling / ODR choices.
//
#include "bmp390_sensor.h"

#include <Adafruit_BMP3XX.h>
#include <Wire.h>

static Adafruit_BMP3XX bmp;
static bool    sensorUp   = false;
static uint8_t sensorAddr = 0;

// The two addresses a BMP390 can present, depending on how SDO is strapped.
static const uint8_t kCandidateAddrs[] = { BMP390_I2C_ADDR,
                                           (BMP390_I2C_ADDR == 0x77) ? 0x76 : 0x77 };

// Pokes one address and returns the raw Wire status code:
//   0 = a device acknowledged
//   2 = clean NACK - the bus is working, there is simply nobody at this address
//   anything else = bus-level failure (stuck line, no pull-ups, arbitration
//                   loss). This distinction is the useful one: a bus with no
//                   pull-ups fails every probe, which looks nothing like an
//                   empty-but-healthy bus even though both find zero devices.
static uint8_t probeAddress(uint8_t addr) {
  Wire1.beginTransmission(addr);
  return Wire1.endTransmission();
}

// Pokes one address and reports whether anything acknowledged.
static bool addressResponds(uint8_t addr) {
  return probeAddress(addr) == 0;
}

uint8_t bmp390Address() {
  return sensorAddr;
}

bool bmp390BringUp(const char *role) {
  Serial.println();
  Serial.println(F("==========================================="));
  Serial.print(F("BMP390 bring-up - "));
  Serial.println(role);
  Serial.println(F("==========================================="));

  Serial.printf("I2C bus 1: SDA=GPIO%d SCL=GPIO%d @ %lu Hz\n",
                BMP390_SDA_PIN, BMP390_SCL_PIN, (unsigned long)BMP390_I2C_HZ);

  if (!Wire1.begin(BMP390_SDA_PIN, BMP390_SCL_PIN, BMP390_I2C_HZ)) {
    Serial.println(F("Wire1.begin() FAILED - check the pin numbers above"));
    return false;
  }

  // Scan the whole bus before touching the driver. If the BMP390 is missing
  // this says whether *anything* is out there, which separates "wrong address"
  // from "nothing wired / no pull-ups" without reaching for a scope.
  //
  // The full 7-bit space is probed, not just 0x08-0x77. A BMP390 cannot live
  // in the reserved ranges, but a device that ACKs there is worth knowing
  // about: it means something on the bus is misbehaving, and an ACK anywhere
  // at all proves the wiring and pull-ups are good.
  Serial.println(F("Scanning bus 1, full 7-bit range 0x00-0x7F:"));
  uint8_t  found  = 0;
  uint16_t nacks  = 0;   // clean "nobody home"
  uint16_t faults = 0;   // bus never completed the transaction
  uint8_t  firstFaultCode = 0;

  for (uint8_t addr = 0x00; addr <= 0x7F; addr++) {
    uint8_t rc = probeAddress(addr);
    if (rc == 0) {
      bool reserved = (addr <= 0x07) || (addr >= 0x78);
      Serial.printf("   0x%02X  ACK%s\n", addr,
                    reserved ? "   <- reserved address, not a normal device" : "");
      found++;
    } else if (rc == 2) {
      nacks++;
    } else {
      if (faults == 0) {
        firstFaultCode = rc;
      }
      faults++;
    }
  }

  Serial.printf("   %u device%s found, %u clean NACK%s, %u bus fault%s\n",
                found,  found  == 1 ? "" : "s",
                nacks,  nacks  == 1 ? "" : "s",
                faults, faults == 1 ? "" : "s");

  // Turn those counts into the conclusion they imply, so the console says what
  // to go check rather than leaving three numbers to interpret.
  if (faults > 0) {
    Serial.printf("   Bus-level failures (first Wire code %u): SDA or SCL is not\n",
                  firstFaultCode);
    Serial.println(F("   returning high. Check the pull-ups and that neither line"));
    Serial.println(F("   is shorted to ground or to the other."));
  } else if (found == 0) {
    Serial.println(F("   Every address NACKed cleanly, so the bus is electrically"));
    Serial.println(F("   healthy - pull-ups are present and both lines toggle."));
    Serial.println(F("   Nothing is listening: check the sensor's 3V3 and GND, and"));
    Serial.println(F("   that SDA/SCL go to the pins named above."));
  }

  // Try the configured address first, then the alternate strap. Reporting the
  // fallback rather than hiding it means a board strapped the other way works
  // now and you still know to fix BMP390_I2C_ADDR.
  for (uint8_t i = 0; i < sizeof(kCandidateAddrs); i++) {
    uint8_t addr = kCandidateAddrs[i];
    if (!addressResponds(addr)) {
      continue;
    }
    if (!bmp.begin_I2C(addr, &Wire1)) {
      Serial.printf("0x%02X acknowledged but is not a BMP390 (chip ID mismatch)\n", addr);
      continue;
    }
    sensorAddr = addr;
    sensorUp   = true;
    if (addr != BMP390_I2C_ADDR) {
      Serial.printf("NOTE: found at 0x%02X, not the configured 0x%02X - SDO is strapped\n"
                    "      the other way. Set -DBMP390_I2C_ADDR=0x%02X to match.\n",
                    addr, BMP390_I2C_ADDR, addr);
    }
    break;
  }

  if (!sensorUp) {
    Serial.printf("BMP390 NOT FOUND at 0x%02X or 0x%02X.\n",
                  kCandidateAddrs[0], kCandidateAddrs[1]);
    Serial.println(F("Check SDA/SCL, 3V3, GND, and that the bus has pull-ups."));
    return false;
  }

  Serial.printf("BMP390 up at 0x%02X\n", sensorAddr);

  // Each of these validates against the others inside the Bosch driver, so a
  // rejected setting means the combination is unachievable, not a bus fault.
  if (!bmp.setPressureOversampling(BMP390_PRESSURE_OVERSAMPLING) ||
      !bmp.setTemperatureOversampling(BMP390_TEMPERATURE_OVERSAMPLING) ||
      !bmp.setIIRFilterCoeff(BMP390_IIR_COEFF) ||
      !bmp.setOutputDataRate(BMP390_ODR)) {
    Serial.println(F("Sensor configuration REJECTED - the oversampling and ODR"));
    Serial.println(F("combination is not achievable. Lower the ODR or the"));
    Serial.println(F("oversampling (see bmp390_sensor.h)."));
    sensorUp = false;
    return false;
  }

  Serial.println(F("Config: pressure x8, temperature x2, IIR coeff 3, ODR 25 Hz"));
  Serial.printf("Altitude reference: %.2f hPa\n", (double)BMP390_SEA_LEVEL_HPA);

  // The first conversion after configuration runs with an unfilled IIR filter,
  // so throw it away rather than reporting a settling value as a measurement.
  bmp.performReading();

  Serial.println(F("-------------------------------------------"));
  return true;
}

Bmp390Reading bmp390Read() {
  Bmp390Reading r = { false, 0.0f, 0.0f, 0.0f };

  if (!sensorUp || !bmp.performReading()) {
    return r;
  }

  r.valid        = true;
  r.pressurePa   = bmp.pressure;
  r.temperatureC = bmp.temperature;

  // Barometric formula, same one Adafruit_BMP3XX::readAltitude uses. Computed
  // here from the reading we already have rather than calling readAltitude(),
  // which would trigger a second conversion for the same sample.
  float ratio = (r.pressurePa / 100.0f) / BMP390_SEA_LEVEL_HPA;
  r.altitudeM = 44330.0f * (1.0f - powf(ratio, 1.0f / 5.255f));

  return r;
}

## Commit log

2026-09-11 Add design spec
    Full architecture for the elevator floor tracker: barometer node in the car
    decides the floor locally and broadcasts over LoRa to a floor-5 bridge, which
    floods it over ESP-NOW to a display on every floor.
    Two findings shaped the design:
    * ALGORITHM.md records the field run as SF10/BW125, but elevatormons'
    platformio.ini sets BW62.5. BW125 is the configuration with in-shaft
    evidence and costs 297 ms per packet against 725 ms, so this project uses
    it at 22 dBm - 8 dB more margin than the run that measured 5.21% loss.
    * A flat 2 s cadence is a 15-50% TX duty cycle and burns the month in under
    three weeks. Gating on the algorithm's own moving flag, plus li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
2026-09-11 Wire formats, the C++ algorithm port, and a replay harness
    floor_monitor.h is a literal port of elevatormons/tools/floor_algorithm.py:
    same function names, same order, every tuning constant from ALGORITHM.md
    section 7 unchanged. double throughout, population std, fixed 64-entry tables
    in place of the dicts, no allocation - so the native environment compiles the
    exact code the ESP32 runs.
    Verified by streaming the real 3.04 h capture through it and diffing against
    the Python sample by sample: floor sequence identical over all 10950 samples,
    10 floors, 2.870 m pitch, 3408.3 m travelled. 49 wire-format unit tests pass.
    Corrects two acceptance gates. ALGORITHM.md section 5 reports 356 trips an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
    [filled_capture.csv, golden_broadcasts.csv]
2026-09-11 Trim the parts list to what actually gets bought
    The Wio-SX1262 ships with its antenna, the enclosure and the ten display
    mounts are printed, and four parts came off: the divider filter cap, the buck
    input electrolytic, the inline fuse, and the barrel connector.
    Two of those had to be paid for somewhere else rather than just deleted:
    * No cap across the divider means the ADC noise is rejected in software.
    batteryReadMv now takes the median of its 32 samples instead of the mean -
    the S3's SAR ADC throws occasional wild readings, and one of those drags a
    mean by its full error while leaving a median alone.
    * No fuse means the pack's BMS is the only overcurrent protection, wh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
    [battery.cpp, display_ui.cpp]
2026-09-11 Firmware and documentation, work in progress
    Snapshot taken while the build-review and doc-consistency passes are still
    running, so that nothing is lost to a machine sleeping. Reviewed findings and
    any consistency fixes land in the next commit.
    [bmp390_sensor.cpp, bmp390_sensor.h, bridge_rx.cpp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]
2026-09-11 Documentation, and the inconsistencies writing it turned up
    Five documents: HARDWARE (assembly, the buck procedure, the divider and its
    calibration), FLASHING (twelve boards, and the XIAO and CYD reset quirks that
    make a silent console look like a dead board), PROTOCOL (both wire formats
    with worked hex dumps), MESH (the flood and how to debug it in a stairwell),
    and ALGORITHM_PORT (the correspondence to the Python and the evidence).
    Writing them against the code found seven things the code and spec had wrong,
    which is most of the value:
    * crc16.h still credited ping_packet.h and baro_packet.h as its consumers.
    Neither exists here - it was carried over from elevatormons, and the only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
    [floor_monitor.h]
2026-09-11 Fix the reviewed defects, and correct the power arithmetic
    An adversarial review across four lenses found eleven defects. The ones that
    mattered were all in failure paths, which is where everything here had been
    verified least.
    Three reviewers independently found the same power bug: with the BMP390 absent
    at boot, the probe deadline was never advanced, so nextDeadline() sat
    permanently in the past, sleepUntil() declined every nap, and the node spun at
    full clock forever. A car node with a loose I2C connector would flatten a 10 Ah
    pack in days instead of reporting a fault for a month.
    Two defeated the NaN hardening added earlier. floor_monitor.h rejects
    non-finite samples and raises a flag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
    [display_ui.h, elevator_tx.cpp, floor_display.cpp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]
2026-09-13 Make a low battery impossible to miss, and fix when it warns
    The warning was a small orange bar in the right pane, and it fired at 12.0 V
    believing that was ~20% remaining. On LiFePO4's flat curve 12.0 V is nearer
    10%, which at ~23 mA is under two days of notice.
    Thresholds (battery.h), decided on the transmitter:
    < 12.8 V LOW, ~20%, ~3.5 days - amber CHARGE SOON badge replaces the bar
    < 12.0 V CRITICAL, ~10%, <2 days - steady red CHARGE BATTERY banner across
    the bottom, and the LED steady red
    The level latches. It escalates on the first reading past a threshold and
    clears only at 13.3 V, i.e. after a charge. A plain comparison would flicker in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
    [battery.cpp, display_ui.cpp, display_ui.h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]
2026-09-13 After a reboot, show "--" until the car has been to both ends
    The transmitter restored its whole saved state on boot, position included,
    and both halves of that position are wrong after a battery swap:
    * The altitude reference is absolute, and weather moves it by metres over
    the hours a pack spends charging (up to ~7 m/h in the capture). The first
    trip was measured against it and could round to the wrong floor.
    * The floor index is only saved every 5 minutes, so even a one-second blip
    restored a stale floor, and a car that ran while the node was dark could
    be anywhere.
    The algorithm has no absolute anchor, so either error was permanent: every
    screen one or more floors o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
    [simmevator-parts-cost.xlsx]
2026-09-16 Power the XIAO through its 5V pad, and price the build
    The 3V3 pad is the output of the XIAO's onboard regulator, so feeding it means
    driving that regulator's output. The buck now lands on the 5V pad instead, which
    is the board's supply input, and the module in the parts list is a 5 V one.
    That regulator is an SGM6029, a synchronous buck with a power-save mode rather
    than a linear part, so the second conversion costs about a tenth of the pack
    rather than the third a linear drop would have. The budget moves from ~56 days
    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
    [simmevator-parts-cost.xlsx]
2026-09-16 Add the KiCad project for the transmitter board
    The schematic, the board, the project's own footprint library, and the
    fp-lib-table that points at it. Backups, the .kicad_prl (per-user display
    state) and KiCad's lock files are gitignored.
    [simmevator_pcb.kicad_pcb, simmevator_pcb.kicad_sch]
2026-09-16 Transmitter schematic: divider, buck header, BMP390 header
    Reviewed against docs/HARDWARE.md and it matches the design:
    * R1 100k / R2 20k, tap on U1 pin 1 (D0 = GPIO1 = ADC1_CH0), R1 taken from
    the +12V net that J1 lands on, so the divider reads the pack and not the
    buck. No capacitor across R2, as designed.
    * J2 pin 3 carries +12V into the buck and pin 2 brings +5V back to U1 pin 14
    (VBUS), which is the 5V pad. U1 pin 12 (3V3_OUT) leaves the XIAO as an
    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
    [simmevator_pcb.kicad_pcb, simmevator_pcb.kicad_sch]
2026-09-18 Transmitter PCB: tighten DRC to fab minimums, export gerbers
    The DRC constraints were at KiCad's permissive defaults, which let the
    router produce geometry no cheap fab will take: 0.2 mm tracks, 0.3 mm
    drills, and zero minimum clearance. Raise the floor to what a standard
    2-layer process quotes without an upcharge - 0.4 mm clearance, 0.4 mm
    track width, 0.4 mm minimum hole and hole clearance - and re-route the
    two segments that violated it.
    Also commits the fabrication output under fab/: back copper, edge cuts,
    the job file and the drill file. They are generated, but they are the
    artifact that actually gets ordered, so pinning them to the board
    revision that produced them is worth the diff.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
    [simmevator_pcb.kicad_pcb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]
2026-09-18 Spec: deploying across three elevators, two with a basement
    Design document for A, B and C, where A and C serve a basement in
    addition to floors 1-10.
    The constraint that shapes it: elevator B must behave exactly as the
    single-elevator system does today. Everything here is either a
    per-elevator build flag or a new screen state that appears only when
    something is misconfigured. Neither wire format changes, the mesh
    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
2026-09-18 Three elevators: per-shaft radio config and a commissioning readout
    Deploys the system across shafts A, B and C, where A and C serve a
    basement in addition to floors 1-10. Elevator B's behaviour is
    unchanged: its frequency, channel and label table are the values the
    single-elevator deployment already ran, and the only thing that differs
    on its wire is a txId byte no display has ever seen.
    Neither wire format changes. The mesh envelope stays at version 1.
    The two links are separated rather than shared. Three cars on one
    frequency is pure ALOHA: at 0.356 packets/s each and a 0.594 s
    vulnerable window, a STATE packet survives two interferers with
    probability exp(-2 x 0.356 x 0.594) = 0.656, s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
    [bridge_rx.cpp, display_ui.cpp, display_ui.h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]
2026-09-18 Docs: three elevators, two of them with a basement
    Brings all five documents up to the three-elevator deployment.
    PROTOCOL.md gains the per-shaft frequency plan and a new section 1.3
    carrying the ALOHA derivation, with the sync-word misconception given
    its own paragraph - it is the most likely wrong idea a future reader
    will have about why the frequencies differ. txId is now ASCII 'A'/'B'/
    'C' in both field tables and in both worked hex dumps, which are now
    stated to be from elevator B. No offset, size, mask or constant was
    touched; neither format changes.
    MESH.md gains the channel plan and the isolation argument, including
    the two pieces of arithmetic a future reader will come looking for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
2026-09-18 Remove the per-shaft header fallbacks that silently meant "elevator B"
    Correcting an overstatement in the previous commit, which claimed the
    header fallbacks were gone. Only ELEV_TX_ID had been given an #error.
    LORA_FREQUENCY in lora_link.h, MESH_CHANNEL in espnow_mesh.h and the
    label pair in display_ui.h still defaulted, and all three defaulted to
    elevator B's values.
    Removing the base-section definitions from platformio.ini was only half
    the job. With these still in place, a build that failed to pick up an
    elevator block compiled cleanly as elevator B - which is precisely the
    silent collapse spec 5.1 asks to be turned into a compile error, just
    relocated from the ini to the headers.
    Each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
    [display_ui.h, lora_link.h]
2026-09-18 Fix a commissioning regression that put healthy parked shafts in ANCHORING
    Found by the adversarial review of this change, and it was a genuine
    regression on elevator B - the shaft this whole change promised not to
    touch.
    The commissioning verdict takes three inputs. Two of them, nFloors and
    nvsRestored, came from STATS. The third, modelReady, came from STATE.
    STATE only runs while the car moves and for STATE_HOLD_AFTER_STOP_MS
    after it stops, so on a display that booted into a parked shaft it was
    false because nothing had arrived - not because the car had said
    anything about its model. Combined with an nFloors that had arrived on
    the 60 s heartbeat, that reads as "full span, not ready", wh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
    [display_ui.h, floor_display.cpp]
2026-09-18 Apply the review's documentation findings, and put LEARNING on the glass
    The adversarial review raised 22 findings across nine dimensions. This
    commit lands the documentation half, plus one display fix that was not
    a documentation problem at all.
    The display fix first, because it is the one a person would have hit.
    The LEARNING screen drew the learned span as bare digits with a small
    "OF 11" caption, and the word LEARNING existed only in a Serial console
    label array - it never reached the glass. The learned span of a shaft
    being commissioned runs 2..11, which is exactly the range of real floor
    labels, drawn in exactly the same seven-segment glyphs. At corridor
    distance a passer-by reads "7"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
    [display_ui.cpp]
